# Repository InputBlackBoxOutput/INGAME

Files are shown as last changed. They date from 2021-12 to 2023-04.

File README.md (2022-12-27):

# INGAME

INGAME is a motion emulator with virtual reality features for playing first person
shooting/adventure games. Virtual reality (VR) is a simulated experience that can be similar to
or completely different from the real world. INGAME has been designed to provide the user
with the feeling of being 'IN-the-GAME'. INGAME is modular in nature and consists of the
following modules.

1. HID module
1. Controller module
1. Pedometer module
1. VR headset

The first three modules listed above have been explained in detail later in the document. The
VR headset provides split stereo video to the user. The following image shows the functional
block diagram of the INGAME system 

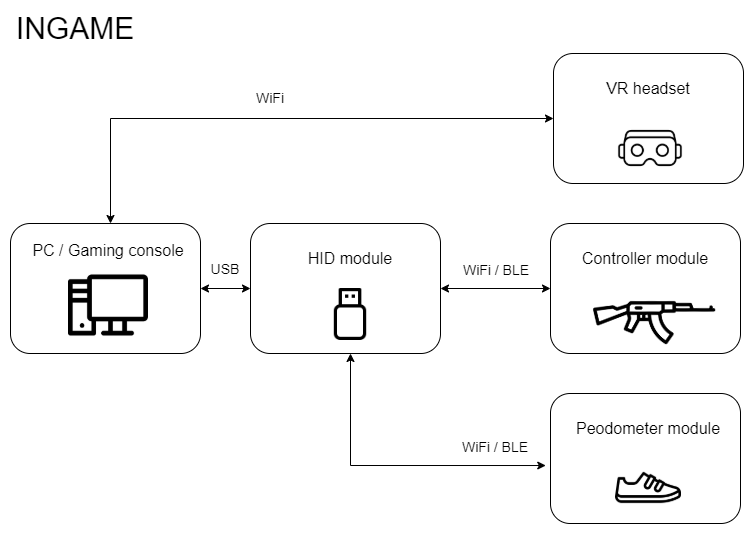
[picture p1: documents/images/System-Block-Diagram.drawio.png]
System block diagram


## Salient features
* Modular to support addons
* Tangle free gaming since the entire system is wireless
* Adaptable to any first person shooting/adventure game
* Minimal lag during gaming due to high-speed data transfer
* Power saving mode to make the battery last longer
* Product certifications: CE certified and ROHS compliant 

## HID module 

### Functions 
- Act as a wireless gateway between the modules worn by the user and the computer
- Connect with the computer via USB as an HID device
- Receive data wirelessly and then map the data to controls of the selected game and send appropriate key strokes to the computer
- Switch the game controls mapping depending on the user selected game
- Display a menu showing information about the system

## Controller module

### Functions
- Connect with the HID module wirelessly
- Send data associated with a button when a button is pressed
- Read IMU data, compute equivalent mouse movement and send the data to the HID module
- Calibrate the IMU device when the calibration button is pressed
- Monitor battery level and sound a buzzer when the battery is low
- Switch to power saving mode upon user inactivity
- [Optional] Control a vibration motor to simulate gunfire which increases in intensity per trigger button press

## Pedometer module

### Functions
- Connect with the HID module wirelessly
- Read accelerometer data, detect steps and send the data to the HID module
- Calibrate the IMU device when the calibration button is pressed
- Monitor battery level and sound a buzzer when the battery is low
- Switch to power saving mode upon user inactivity

### Made with lots of ⏱️, 📚 and ☕ by InputBlackBoxOutput

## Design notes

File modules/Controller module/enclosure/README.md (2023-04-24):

# Enclosure for controller module

- Option 1: 3D print the toy rifle using the 3D model files in this directory after modification to hold all the PCBs

- Option 2: Buy toy rifles from thrid party and then 3D print modifications to hold all PCBs

|#| Vendor |
|--|--|
|1|https://www.alibaba.com/product-detail/95cm-length-big-operated-lithium-battery_1600554537975.html|
|2|https://www.alibaba.com/product-detail/Boxu-416D-F668-Electric-M416-Toy_1600747761612.html|

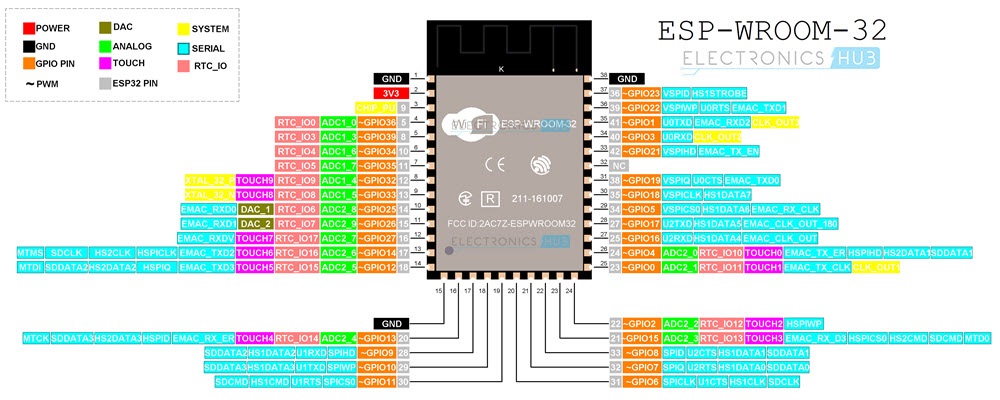
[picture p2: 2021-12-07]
documents/reference circuits/ESP-WROOM-32-Pinout.jpg

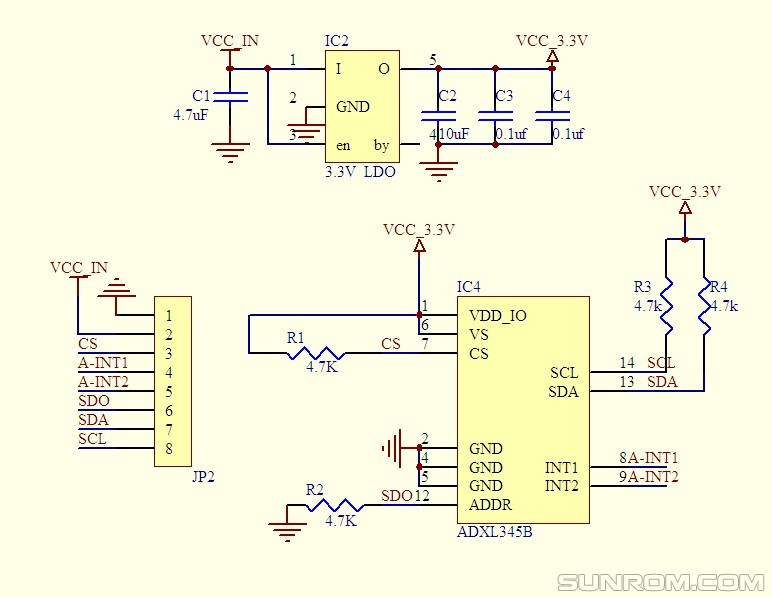
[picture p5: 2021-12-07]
documents/reference circuits/ADXL345 - Accelerometer.jpg

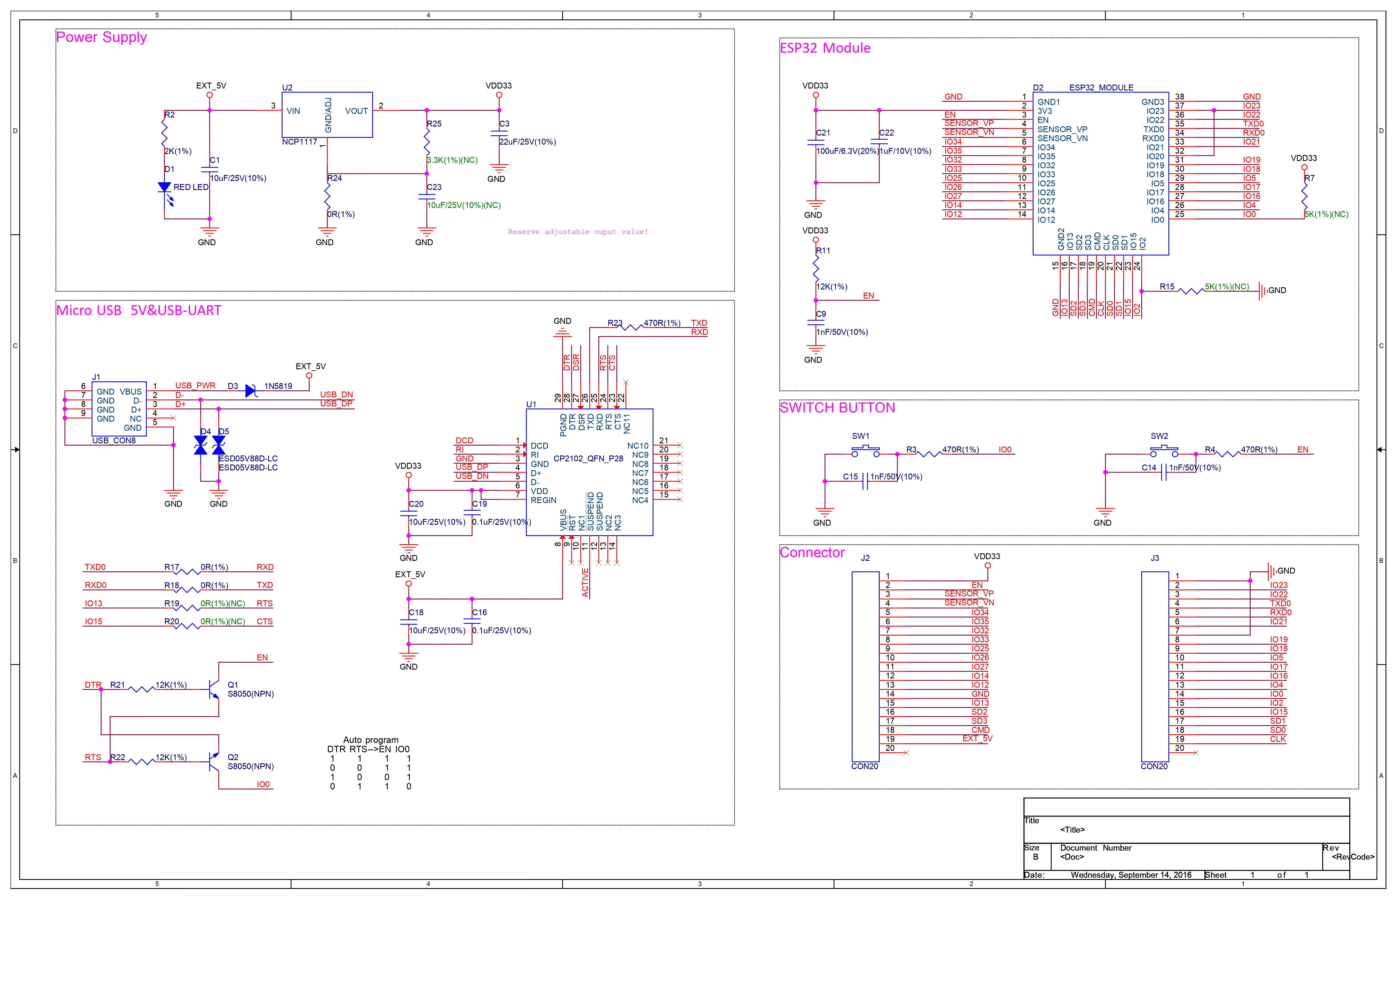
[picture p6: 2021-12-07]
documents/reference circuits/ESP32 - Dev Kit C.jpg

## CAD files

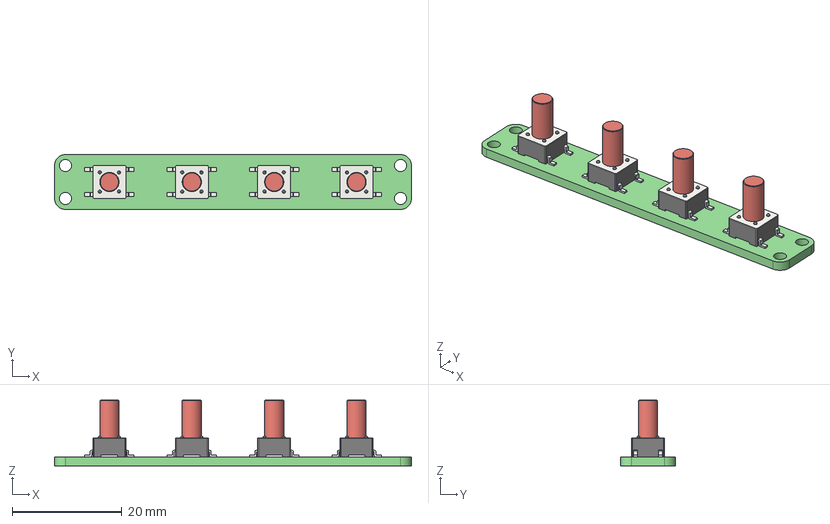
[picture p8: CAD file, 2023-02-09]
modules/Controller module/button-board-1/board.step
65.0 x 10.0 x 12.0 mm

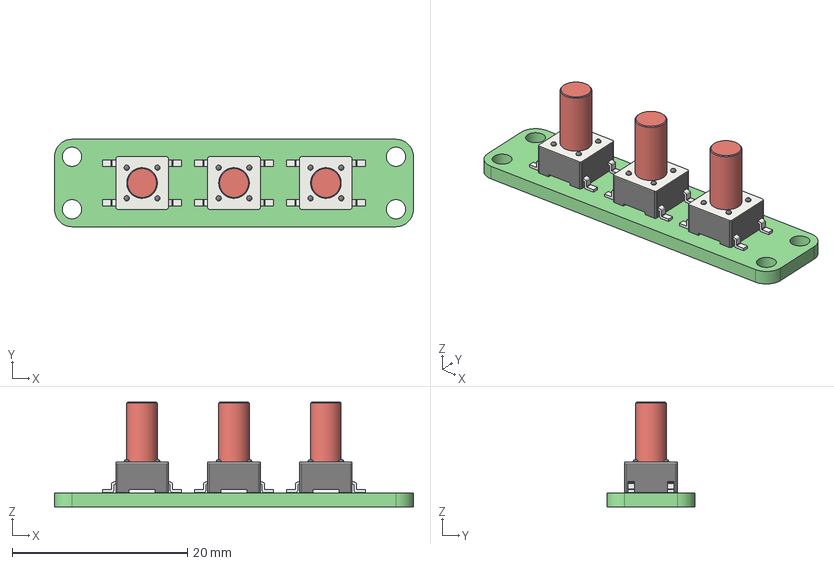
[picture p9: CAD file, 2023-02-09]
modules/Controller module/button-board-2/board.step
41.0 x 10.0 x 12.0 mm

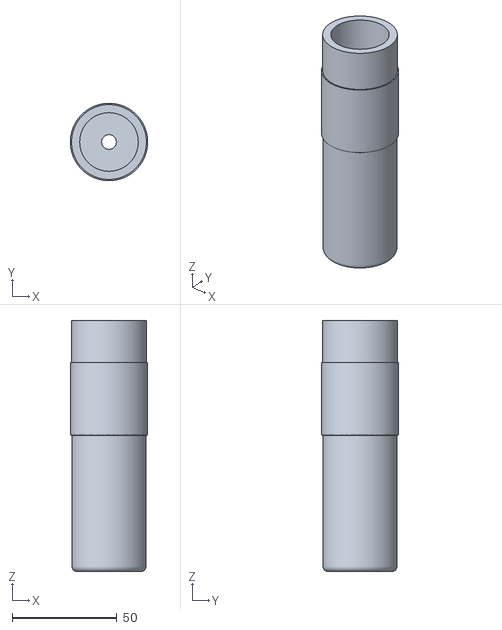
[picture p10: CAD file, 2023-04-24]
modules/Controller module/enclosure/3D-model-files/Suppressor.stl
37.0 x 37.0 x 120.0

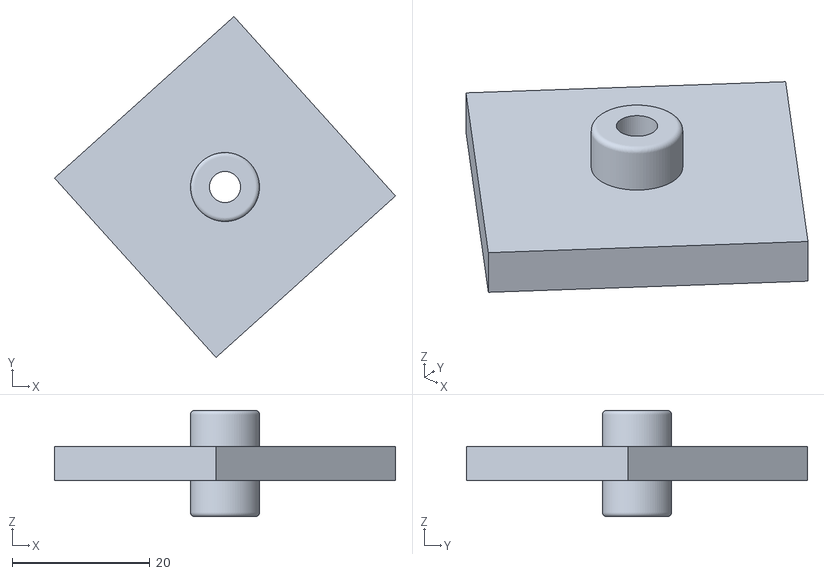
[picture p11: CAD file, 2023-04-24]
modules/Controller module/enclosure/3D-model-files/Gear.stl
49.4 x 49.4 x 15.4

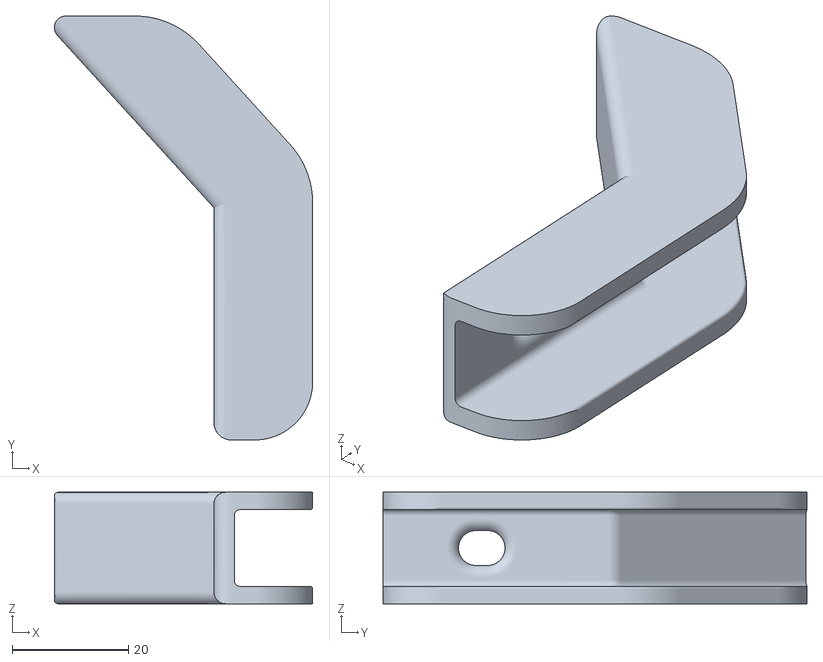
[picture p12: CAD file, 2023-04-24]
modules/Controller module/enclosure/3D-model-files/Stock_lever.stl
44.5 x 73.0 x 19.2

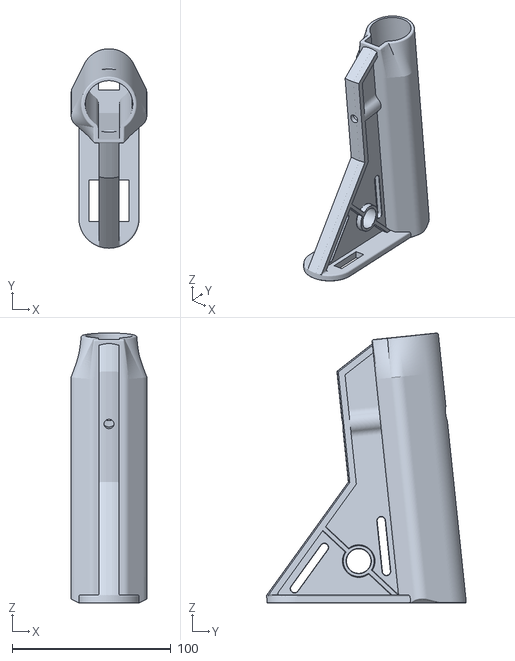
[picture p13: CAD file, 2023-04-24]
modules/Controller module/enclosure/3D-model-files/Stock_body.stl
47.6 x 125.6 x 170.0

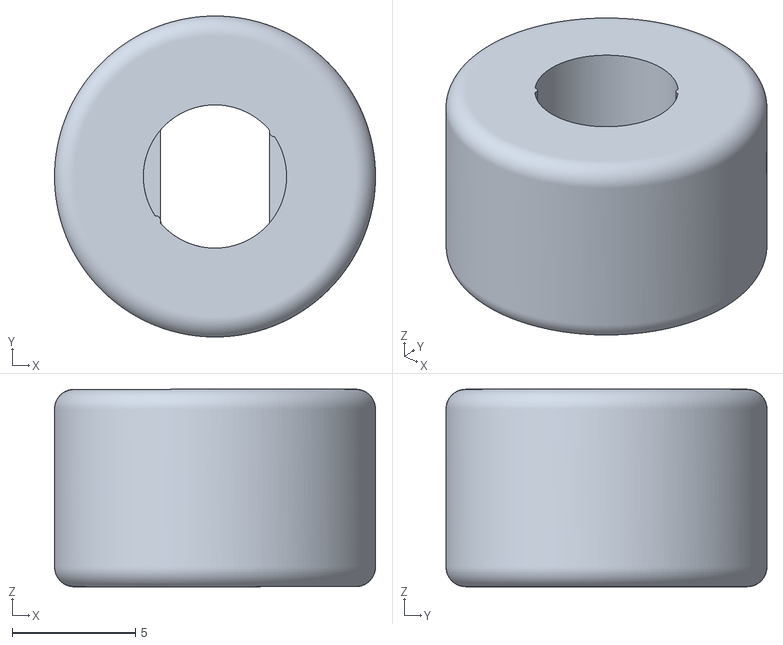
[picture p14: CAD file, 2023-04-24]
modules/Controller module/enclosure/3D-model-files/Stock_pin_cap.stl
13.0 x 13.0 x 8.01

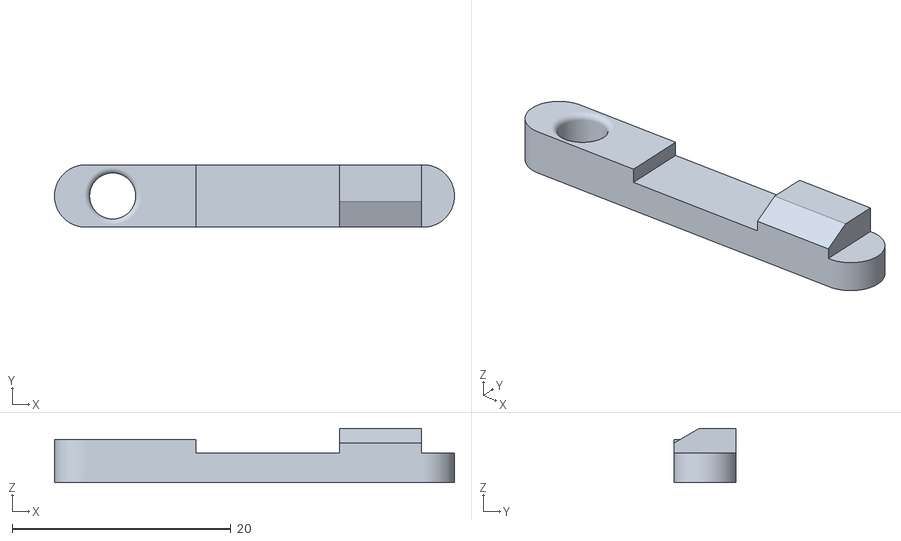
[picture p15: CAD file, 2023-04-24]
modules/Controller module/enclosure/3D-model-files/Magcatch.stl
36.5 x 5.70 x 4.96

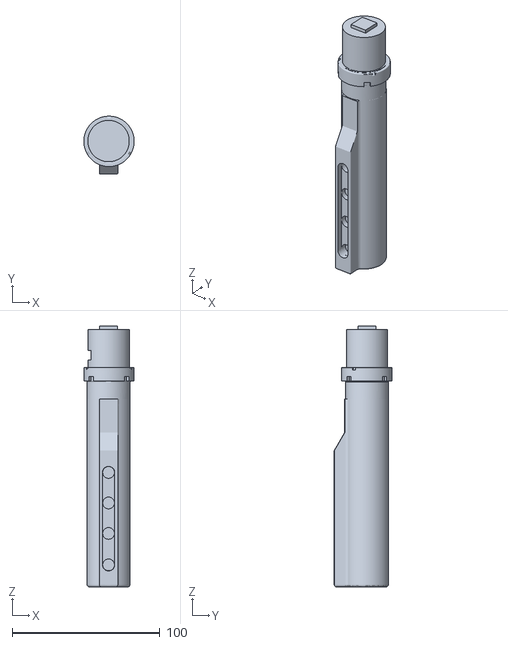
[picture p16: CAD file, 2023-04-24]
modules/Controller module/enclosure/3D-model-files/Buffer_tube.stl
34.1 x 39.0 x 176.7

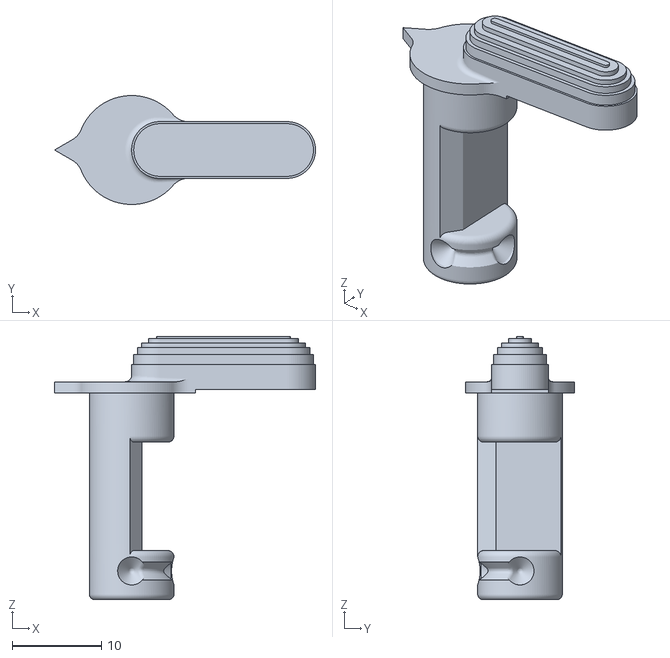
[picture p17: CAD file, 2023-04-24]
modules/Controller module/enclosure/3D-model-files/Safety.stl
29.2 x 12.2 x 29.5

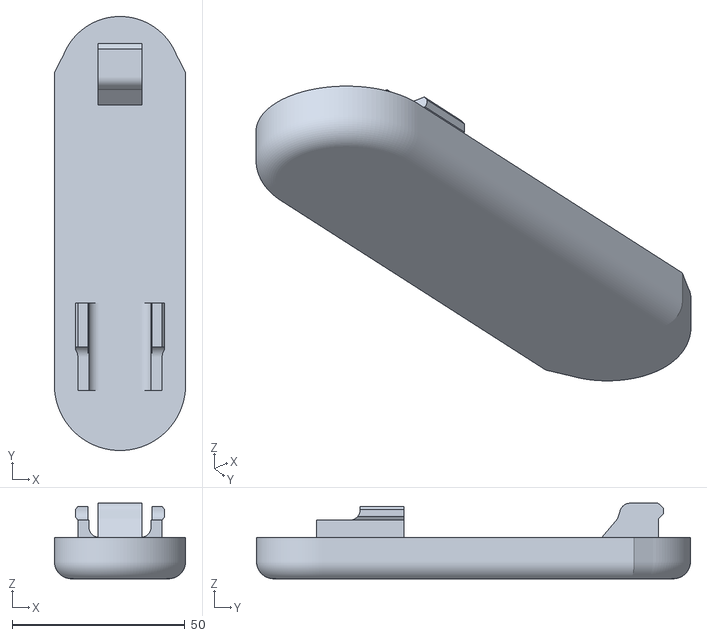
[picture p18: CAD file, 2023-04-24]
modules/Controller module/enclosure/3D-model-files/Stock_pad.stl
38.0 x 125.6 x 21.9

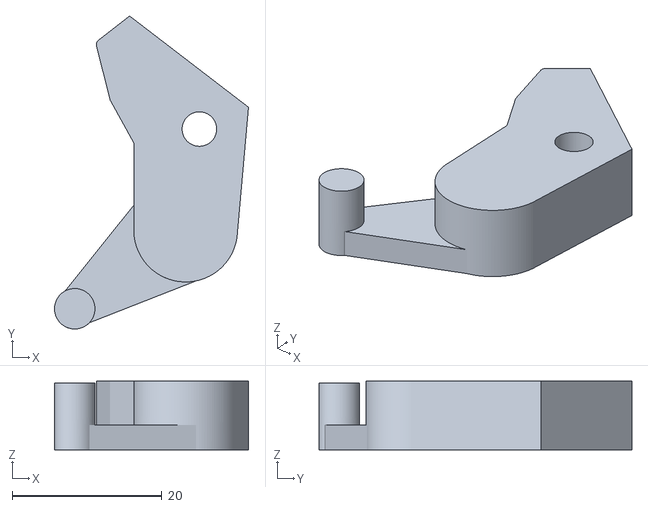
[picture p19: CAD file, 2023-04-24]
modules/Controller module/enclosure/3D-model-files/Disconnector.stl
25.9 x 41.7 x 9.17

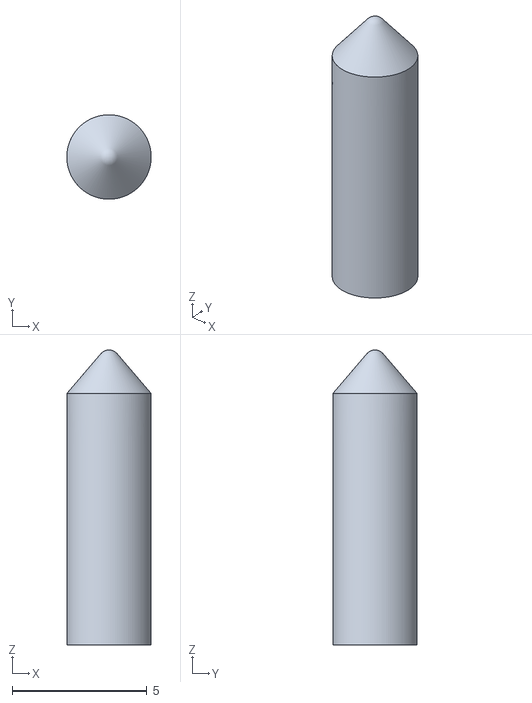
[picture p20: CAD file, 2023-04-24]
modules/Controller module/enclosure/3D-model-files/Safety_detent.stl
3.13 x 3.13 x 10.9

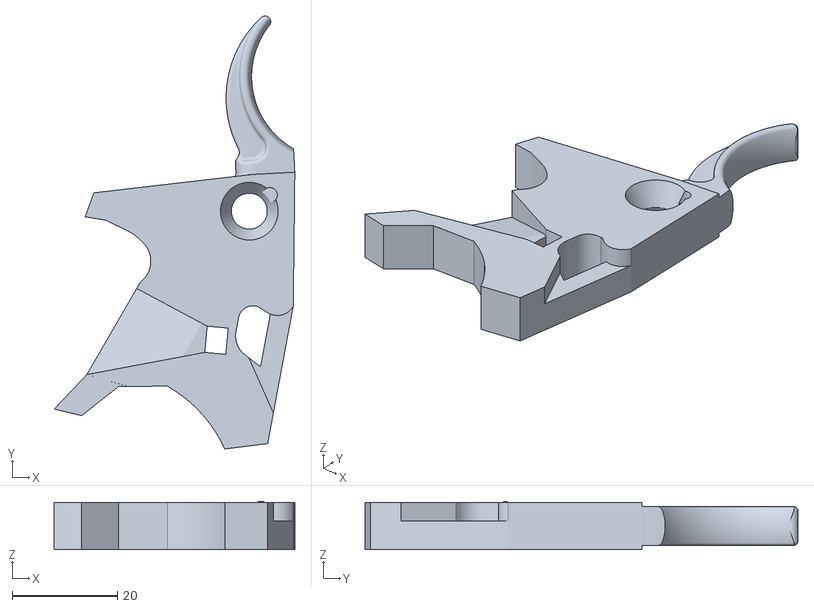
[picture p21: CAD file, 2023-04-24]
modules/Controller module/enclosure/3D-model-files/Trigger.stl
45.7 x 82.2 x 9.17

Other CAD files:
modules/Controller module/enclosure/3D-model-files/Handguard_plug.stl
modules/Controller module/enclosure/3D-model-files/Magcatch_button.stl
modules/Controller module/enclosure/3D-model-files/End_plate.stl
modules/Controller module/enclosure/3D-model-files/Trigger_guard.stl
modules/Controller module/enclosure/3D-model-files/Handguard.stl
modules/Controller module/enclosure/3D-model-files/Stock_pin.stl
modules/HID module/enclosure.f3d
modules/Pedometer module/enclosure.f3d

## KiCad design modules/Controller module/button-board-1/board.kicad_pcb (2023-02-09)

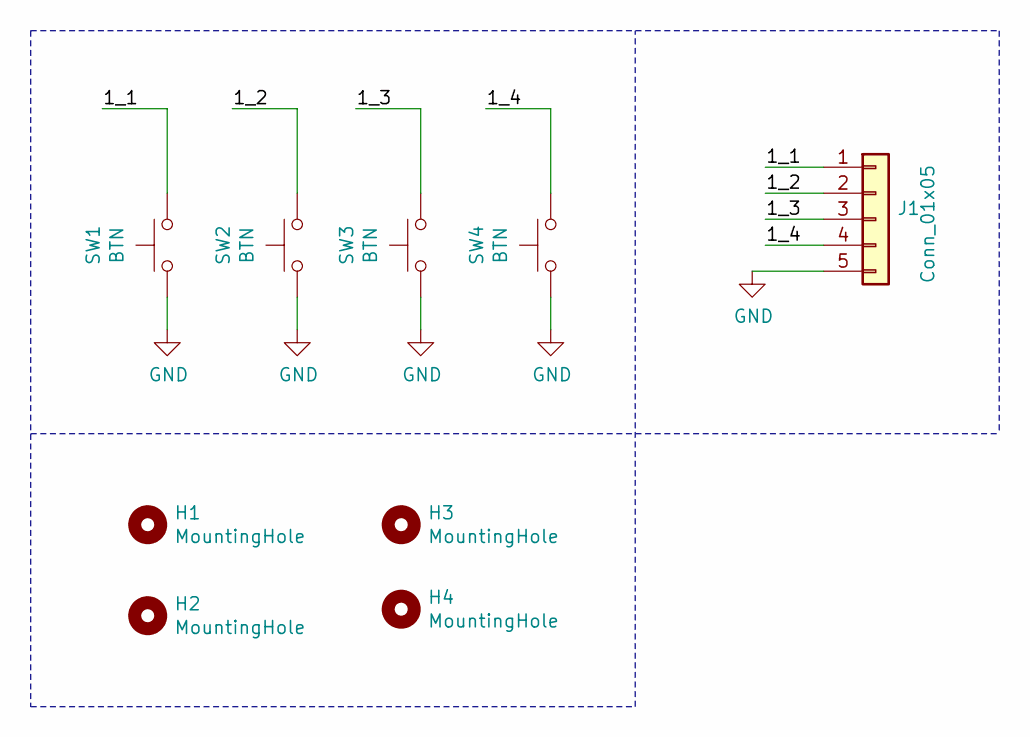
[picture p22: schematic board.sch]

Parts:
H1, H2, H3, H4: MountingHole; MountingHole_2.2mm_M2
J1: Conn_01x05; SolderWire_1x05_P2.54mm
SW1, SW2, SW3, SW4: BTN; SW_SPST_Omron_B3FS-100xP

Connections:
/1_1: J1.1, SW1.2
/1_2: J1.2, SW2.2
/1_3: J1.3, SW3.2
/1_4: J1.4, SW4.2
GND: J1.5, SW1.1, SW2.1, SW3.1, SW4.1

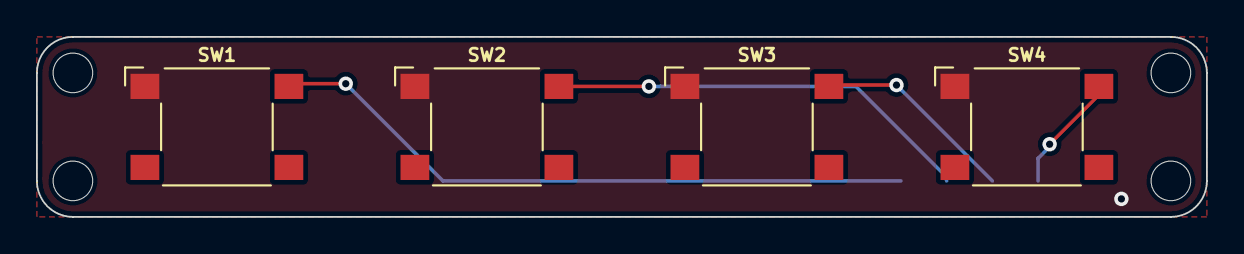
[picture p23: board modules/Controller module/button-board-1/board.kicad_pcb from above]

Board: 2 copper layers, 65.0 x 10.0 mm, 9 parts (1 on the bottom side), 5 nets.

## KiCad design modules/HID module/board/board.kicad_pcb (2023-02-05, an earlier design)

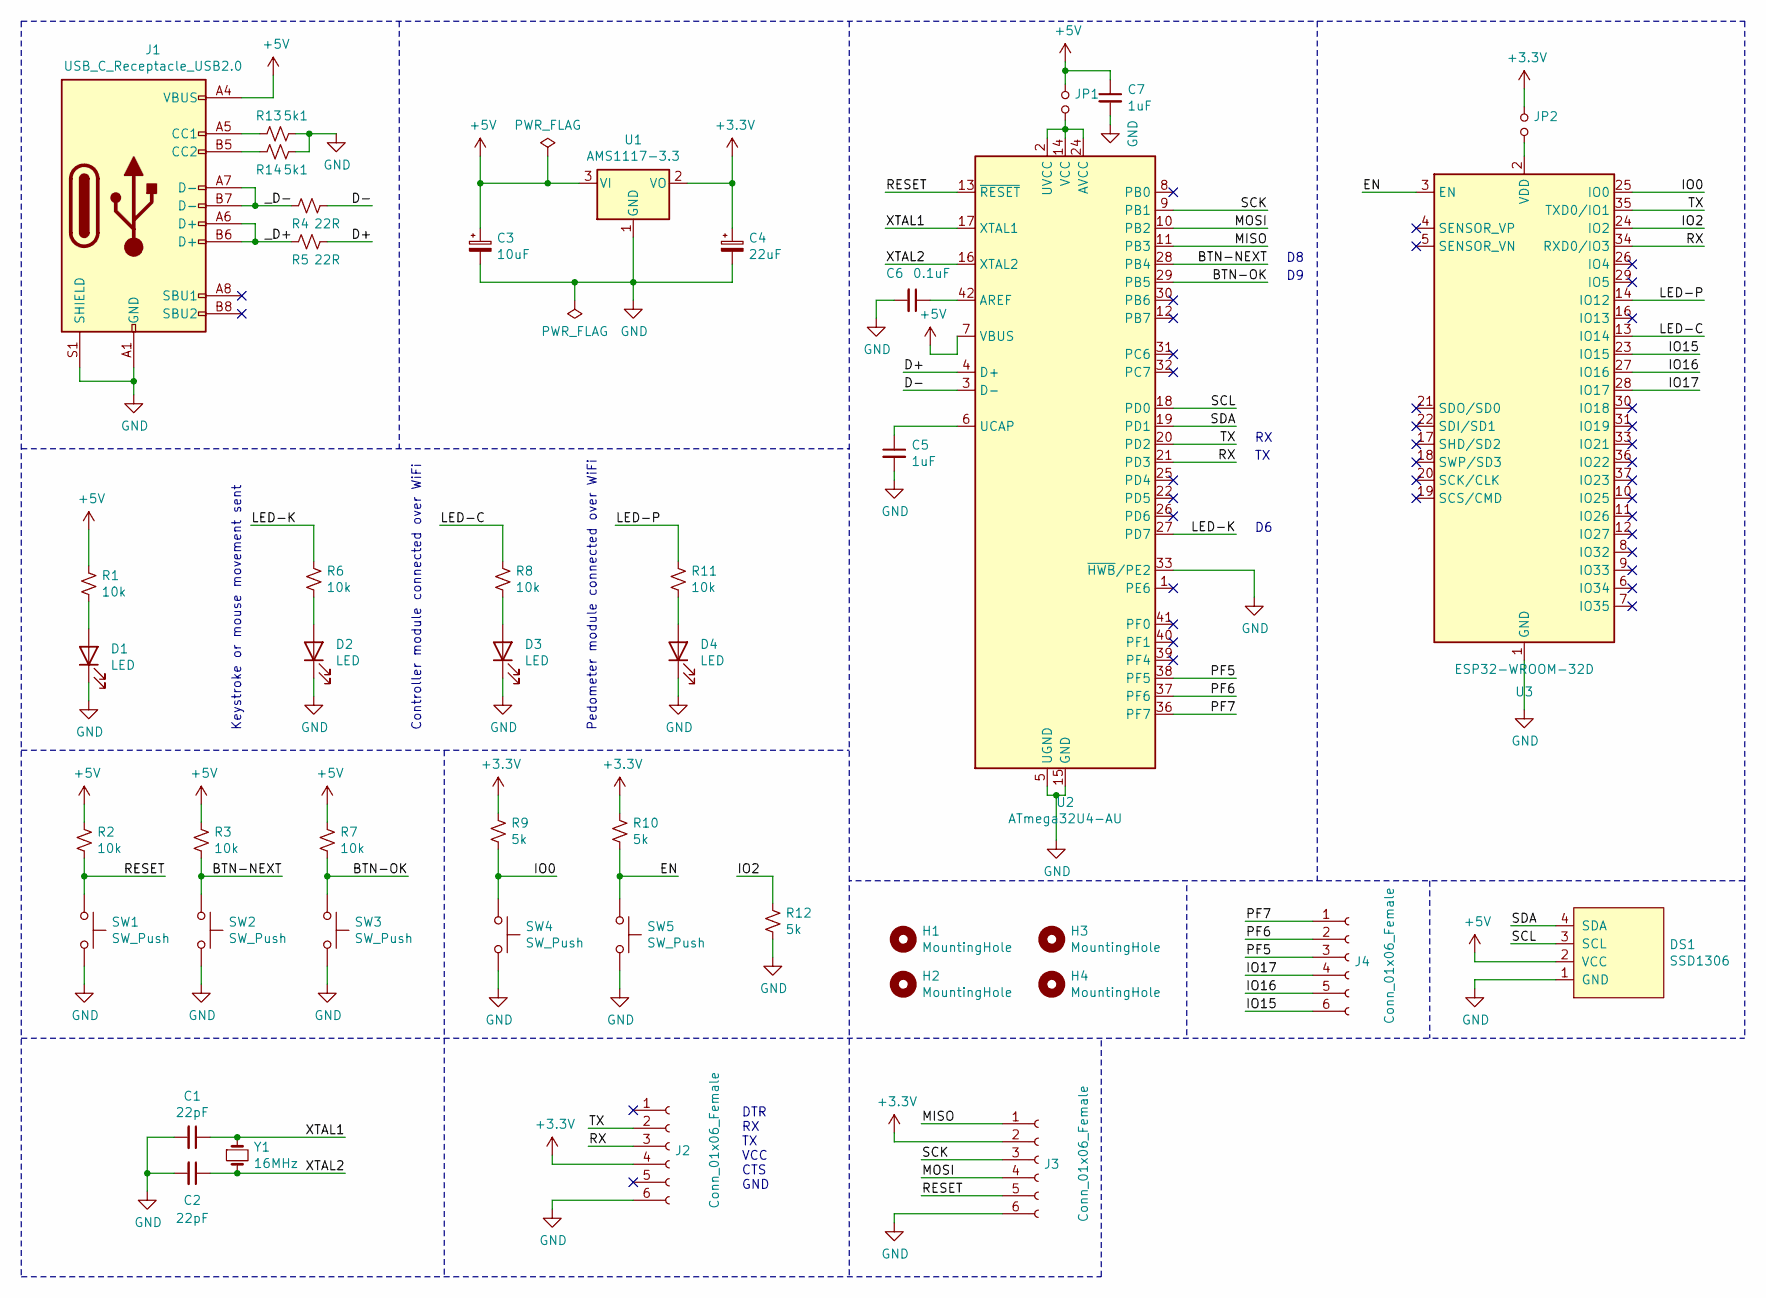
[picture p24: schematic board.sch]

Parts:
C1, C2: 22pF; C_0805_2012Metric_Pad1.18x1.45mm_HandSolder
C3: 10uF; C_0805_2012Metric_Pad1.18x1.45mm_HandSolder
C4: 22uF; C_0805_2012Metric_Pad1.18x1.45mm_HandSolder
C5, C7: 1uF; C_0805_2012Metric_Pad1.18x1.45mm_HandSolder
C6: 0.1uF; C_0805_2012Metric_Pad1.18x1.45mm_HandSolder
D1, D2, D3, D4: LED; LED_0805_2012Metric_Pad1.15x1.40mm_HandSolder
DS1: SSD1306; 128x64OLED
H1, H2, H3, H4: MountingHole; MountingHole_2.2mm_M2
J1: USB_C_Receptacle_USB2.0; USB_C_Receptacle_HRO_TYPE-C-31-M-12
J2, J3, J4: Conn_01x06_Female; SolderWire_1x06_P2.54mm
JP1, JP2: Jumper_NO_Small; SolderJumper-2_P1.3mm_Open_RoundedPad1.0x1.5mm
R1, R2, R3, R6, R7, R8, R11: 10k; R_0805_2012Metric_Pad1.20x1.40mm_HandSolder
R4, R5: 22R; R_0603_1608Metric
R9, R10, R12: 5k; R_0805_2012Metric_Pad1.20x1.40mm_HandSolder
R13, R14: 5k1; R_0603_1608Metric
SW1, SW4, SW5: SW_Push; SW_SPST_B3U-1000P
SW2, SW3: SW_Push; SW_SPST_Omron_B3FS-100xP
U1: AMS1117-3.3; SOT-223-3_TabPin2
U2: ATmega32U4-AU; TQFP-44_10x10mm_P0.8mm
U3: ESP32-WROOM-32D; ESP32-WROOM-32
Y1: 16MHz; Crystal_SMD_HC49-SD

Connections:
+3V3: C4.1, J2.4, J3.2, JP2.1, R9.1, R10.1, U1.2 (VO)
+5V: C3.1, C7.1, DS1.2 (VCC), J1.A4 (VBUS), J1.A9 (VBUS), J1.B4 (VBUS), J1.B9 (VBUS), JP1.1, R1.1, R2.1, R3.1, R7.1, U1.3 (VI), U2.7 (VBUS)
/BTN-NEXT: R3.2, SW2.1, U2.28 (PB4)
/BTN-OK: R7.2, SW3.1, U2.29 (PB5)
/D+: R5.1, U2.4 (D+)
/D-: R4.1, U2.3 (D-)
/EN: R10.2, SW5.1, U3.3 (EN)
/IO0: R9.2, SW4.1, U3.25 (IO0)
/IO2: R12.1, U3.24 (IO2)
/IO15: J4.6, U3.23 (IO15)
/IO16: J4.5, U3.27 (IO16)
/IO17: J4.4, U3.28 (IO17)
/LED-C: R8.1, U3.13 (IO14)
/LED-K: R6.1, U2.27 (PD7)
/LED-P: R11.1, U3.14 (IO12)
/MISO: J3.1, U2.11 (PB3)
/MOSI: J3.4, U2.10 (PB2)
/PF5: J4.3, U2.38 (PF5)
/PF6: J4.2, U2.37 (PF6)
/PF7: J4.1, U2.36 (PF7)
/RESET: J3.5, R2.2, SW1.1, U2.13 (~RESET)
/RX: J2.3, U2.21 (PD3), U3.34 (RXD0/IO3)
/SCK: J3.3, U2.9 (PB1)
/SCL: DS1.3 (SCL), U2.18 (PD0)
/SDA: DS1.4 (SDA), U2.19 (PD1)
/TX: J2.2, U2.20 (PD2), U3.35 (TXD0/IO1)
/XTAL1: C1.1, U2.17 (XTAL1), Y1.1
/XTAL2: C2.1, U2.16 (XTAL2), Y1.2
/_D+: J1.A6 (D+), J1.B6 (D+), R5.2
/_D-: J1.A7 (D-), J1.B7 (D-), R4.2
GND: C1.2, C2.2, C3.2, C4.2, C5.2, C6.2, C7.2, D1.1 (K), D2.1 (K), D3.1 (K), D4.1 (K), DS1.1 (GND), J1.A1 (GND), J1.A12 (GND), J1.B1 (GND), J1.B12 (GND), J1.S1 (SHIELD), J2.6, J3.6, R12.2, R13.1, R14.1, SW1.2, SW2.2, SW3.2, SW4.2, SW5.2, U1.1 (GND), U2.5 (UGND), U2.15 (GND), U2.23 (GND), U2.33 (~HWB~/PE2), U2.35 (GND), U2.43 (GND), U3.1 (GND), U3.15 (GND), U3.38 (GND), U3.39 (GND)
unnamed: C5.1, U2.6 (UCAP)
unnamed: C6.1, U2.42 (AREF)
unnamed: D1.2 (A), R1.2
unnamed: D2.2 (A), R6.2
unnamed: D3.2 (A), R8.2
unnamed: D4.2 (A), R11.2
unnamed: J1.A5 (CC1), R13.2
unnamed: J1.B5 (CC2), R14.2
unnamed: JP1.2, U2.2 (UVCC), U2.14 (VCC), U2.24 (AVCC), U2.34 (VCC), U2.44 (AVCC)
unnamed: JP2.2, U3.2 (VDD)

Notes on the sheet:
Keystroke or mouse movement sent
Controller module connected over WiFi
DTR RX TX VCC CTS GND
Pedometer module connected over WiFi

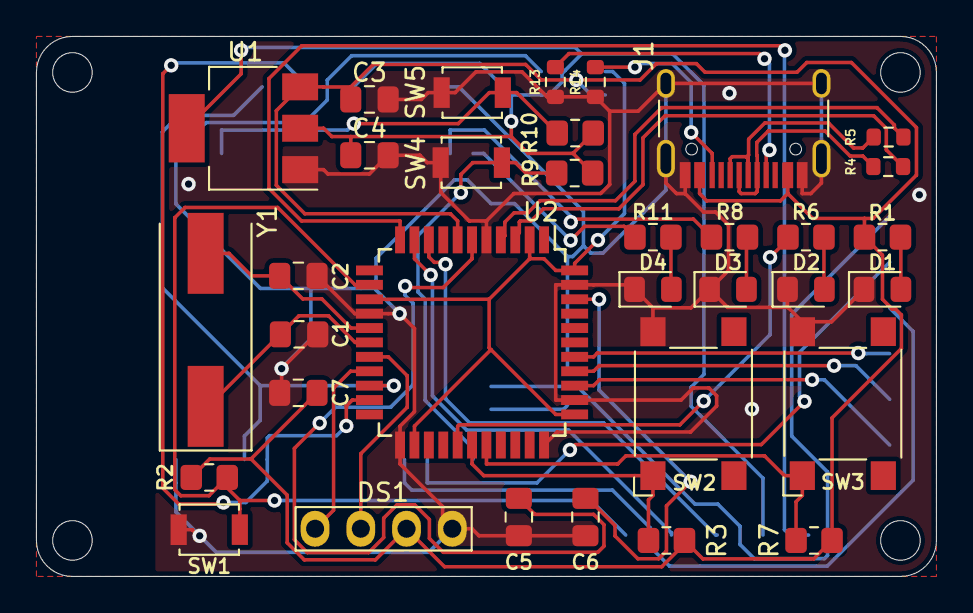
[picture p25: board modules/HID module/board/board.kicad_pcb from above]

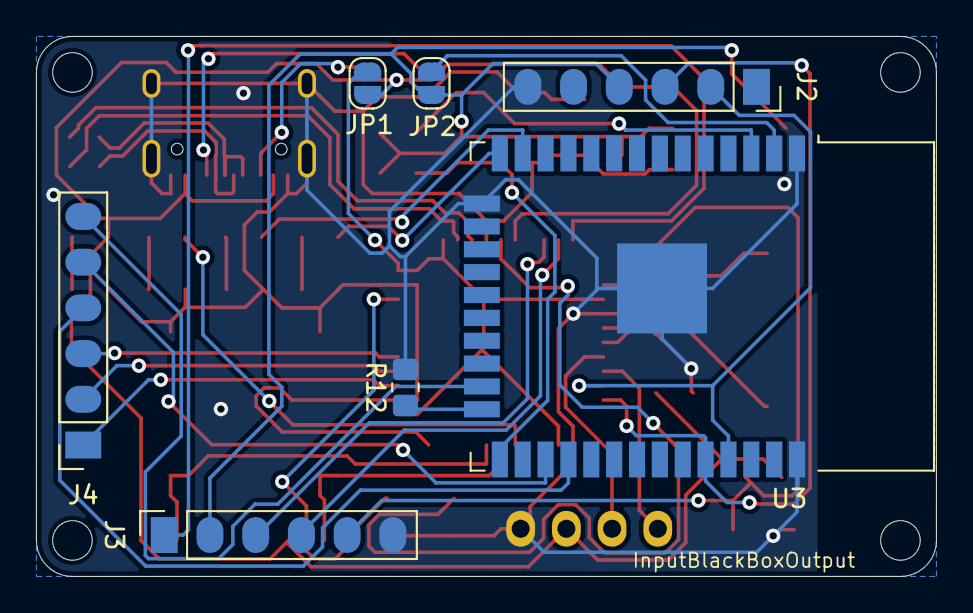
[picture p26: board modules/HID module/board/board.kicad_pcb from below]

Board: 2 copper layers, 50.0 x 30.0 mm, 45 parts (7 on the bottom side), 41 nets.

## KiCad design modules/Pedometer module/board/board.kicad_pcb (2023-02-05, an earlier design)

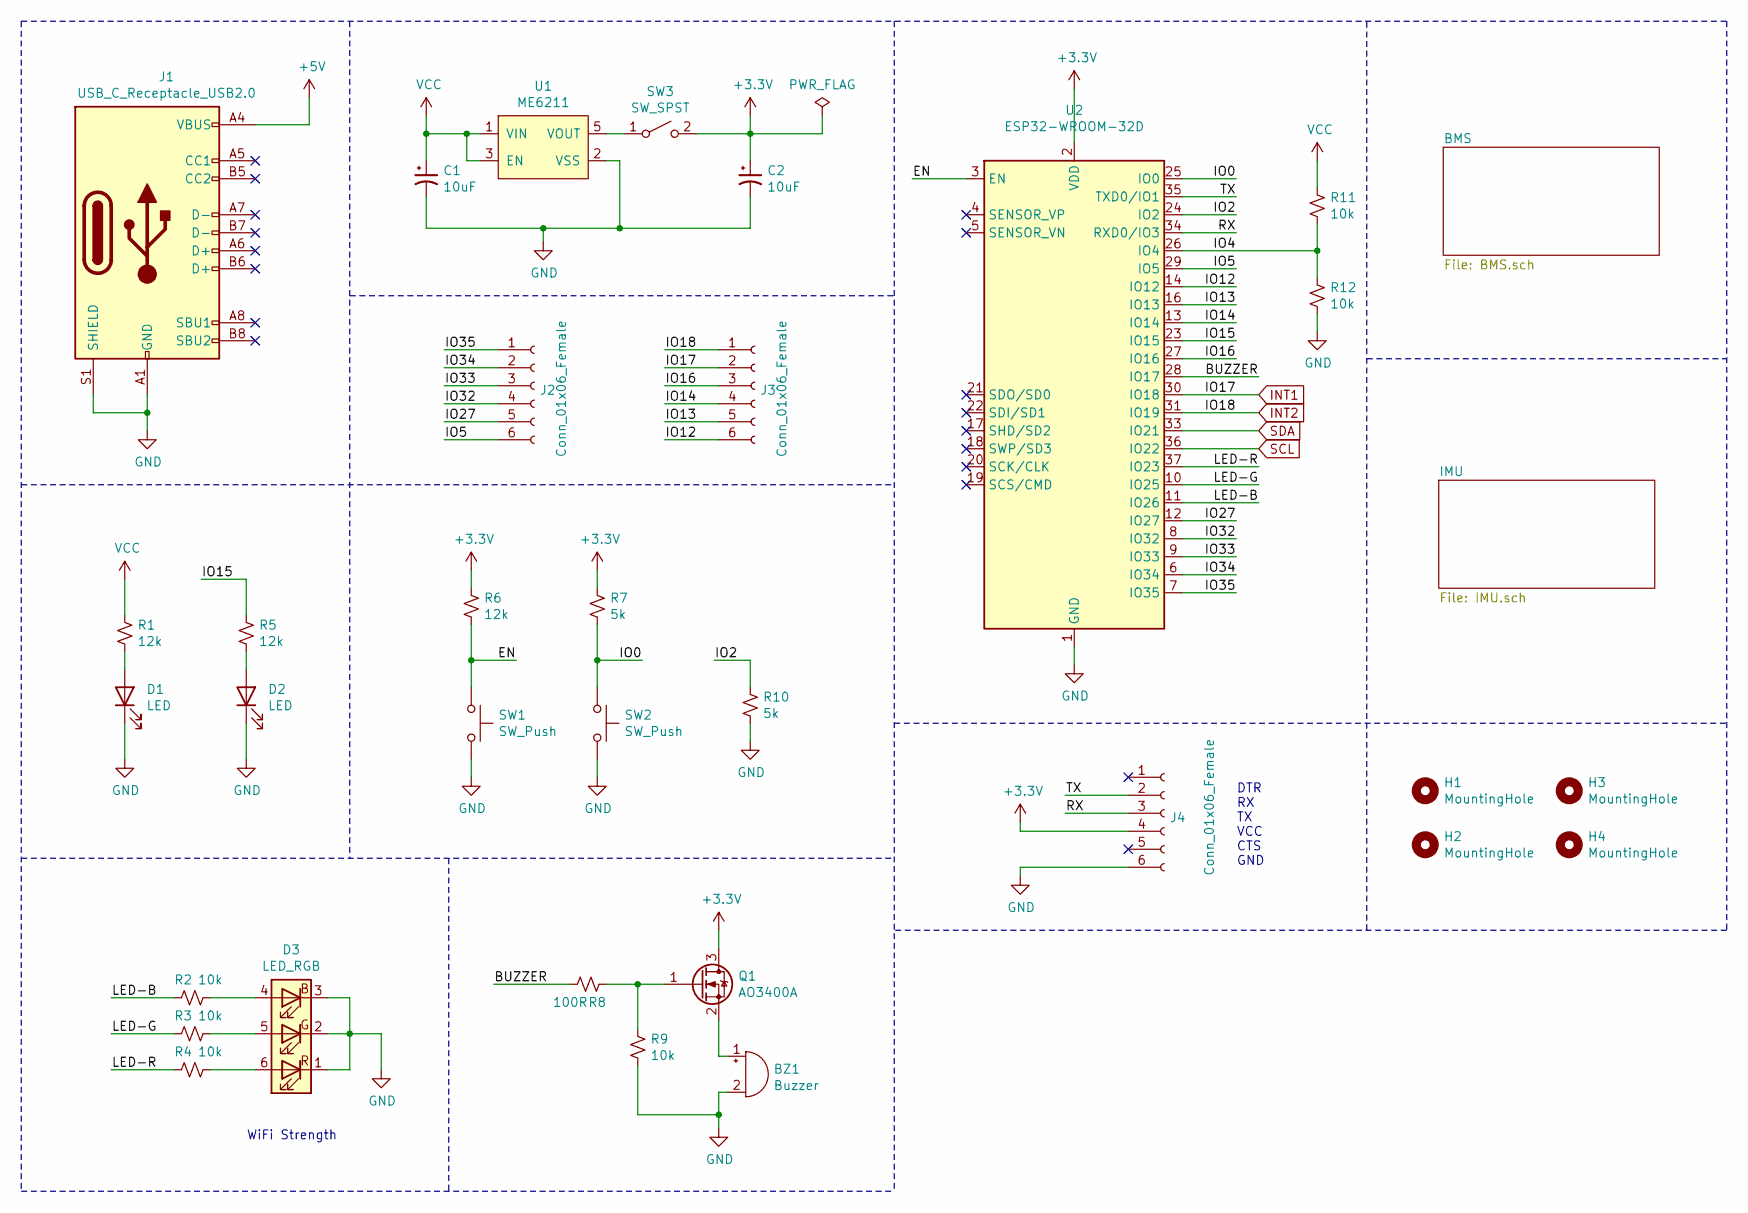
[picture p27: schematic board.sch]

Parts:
BZ1: Buzzer; Buzzer_Murata_PKMCS0909E4000-R1
C1, C2: 10uF; C_0805_2012Metric_Pad1.18x1.45mm_HandSolder
D1, D2: LED; LED_0805_2012Metric_Pad1.15x1.40mm_HandSolder
D3: LED_RGB; LED_RGB_5050-6
H1, H2: MountingHole; MountingHole_2.2mm_M2
H3, H4: MountingHole; MountingHole_2.5mm
J1: USB_C_Receptacle_USB2.0; USB_C_Receptacle_HRO_TYPE-C-31-M-12
J2, J3, J4: Conn_01x06_Female; SolderWire_1x06_P2.54mm
Q1: AO3400A; SOT-23
R1, R5, R6: 12k; R_0805_2012Metric_Pad1.20x1.40mm_HandSolder
R2, R3, R4, R9, R11, R12: 10k; R_0805_2012Metric_Pad1.20x1.40mm_HandSolder
R7, R10: 5k; R_0805_2012Metric_Pad1.20x1.40mm_HandSolder
R8: 100R; R_0805_2012Metric_Pad1.20x1.40mm_HandSolder
SW1, SW2: SW_Push; SW_SPST_B3U-1000P
SW3: SW_SPST; SW-SPDT-PCM12
U1: ME6211; SOT-23-5_HandSoldering
U2: ESP32-WROOM-32D; ESP32-WROOM-32

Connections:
+5V: J1.A4 (VBUS), J1.A9 (VBUS), J1.B4 (VBUS), J1.B9 (VBUS); also elsewhere on the board
/BUZZER: R8.1, U2.28 (IO17)
/EN: R6.2, SW1.1, U2.3 (EN)
/IO0: R7.2, SW2.1, U2.25 (IO0)
/IO2: R10.1, U2.24 (IO2)
/IO4: R11.2, R12.1, U2.26 (IO4)
/IO5: J2.6, U2.29 (IO5)
/IO12: J3.6, U2.14 (IO12)
/IO13: J3.5, U2.16 (IO13)
/IO14: J3.4, U2.13 (IO14)
/IO15: R5.1, U2.23 (IO15)
/IO16: J3.3, U2.27 (IO16)
/IO27: J2.5, U2.12 (IO27)
/IO32: J2.4, U2.8 (IO32)
/IO33: J2.3, U2.9 (IO33)
/IO34: J2.2, U2.6 (IO34)
/IO35: J2.1, U2.7 (IO35)
/LED-B: R2.2, U2.11 (IO26)
/LED-G: R3.2, U2.10 (IO25)
/LED-R: R4.2, U2.37 (IO23)
/RX: J4.3, U2.34 (RXD0/IO3)
/TX: J4.2, U2.35 (TXD0/IO1)
GND: BZ1.2 (+), C1.2, C2.2, D1.1 (K), D2.1 (K), D3.1 (RK), D3.2 (GK), D3.3 (BK), J1.A1 (GND), J1.A12 (GND), J1.B1 (GND), J1.B12 (GND), J1.S1 (SHIELD), J4.6, R9.2, R10.2, R12.2, SW1.2, SW2.2, U1.2 (VSS), U2.1 (GND), U2.15 (GND), U2.38 (GND), U2.39 (GND); also elsewhere on the board
INT1: J3.2, U2.30 (IO18); also elsewhere on the board
INT2: J3.1, U2.31 (IO19); also elsewhere on the board
unnamed: BZ1.1 (-), Q1.2 (S)
unnamed: D1.2 (A), R1.2
unnamed: D2.2 (A), R5.2
unnamed: D3.4 (BA), R2.1
unnamed: D3.5 (GA), R3.1
unnamed: D3.6 (RA), R4.1
unnamed: Q1.1 (G), R8.2, R9.1
unnamed: SW3.1 (A), U1.5 (VOUT)
SCL: U2.36 (IO22); also elsewhere on the board
SDA: U2.33 (IO21); also elsewhere on the board
VCC: C1.1, R1.1, R11.1, U1.1 (VIN), U1.3 (EN); also elsewhere on the board

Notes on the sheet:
DTR RX TX VCC CTS GND
WiFi Strength

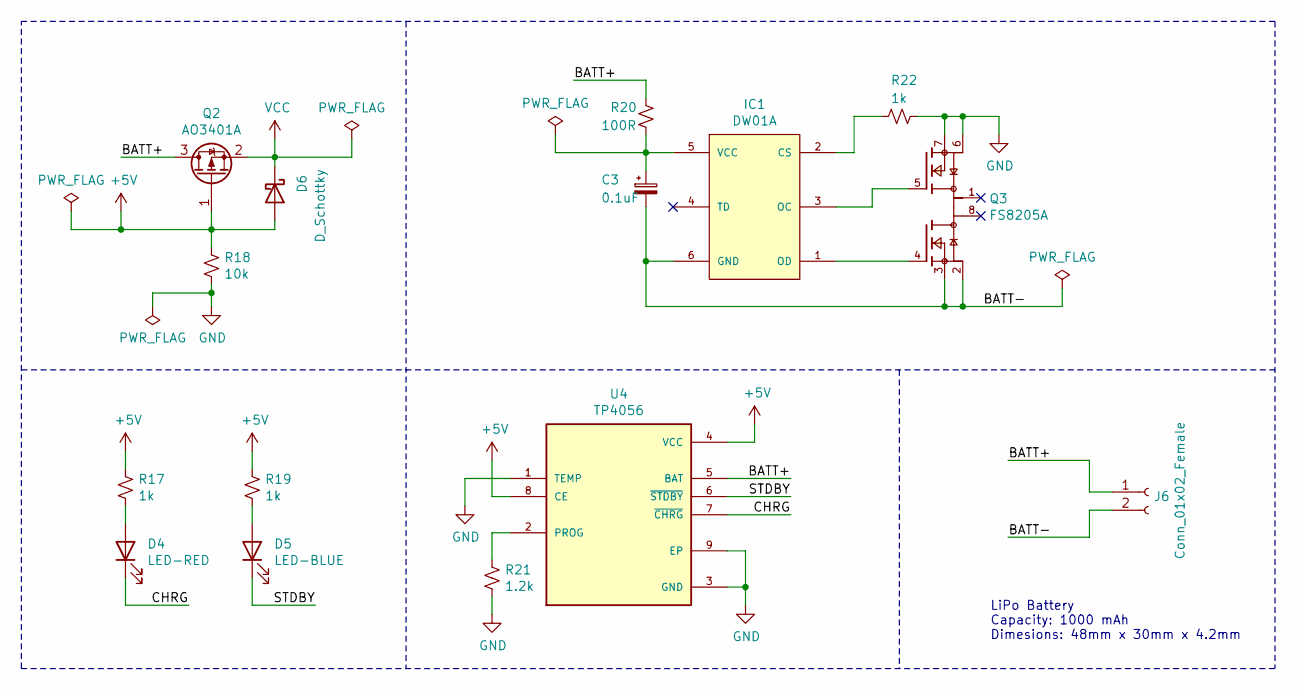
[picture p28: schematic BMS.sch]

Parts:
C3: 0.1uF; C_0805_2012Metric_Pad1.18x1.45mm_HandSolder
D4: LED-RED; LED_0805_2012Metric_Pad1.15x1.40mm_HandSolder
D5: LED-BLUE; LED_0805_2012Metric_Pad1.15x1.40mm_HandSolder
D6: D_Schottky; D_SMA
IC1: DW01A; SOT-23-6_Handsoldering; MPN DW01A; LCSC C351410
J6: Conn_01x02_Female; SolderWire_1x02_P2.00mm
Q2: AO3401A; SOT-23
Q3: FS8205A; SOP65P640X120-8N; PARTREV 1.7
R17, R19, R22: 1k; R_0805_2012Metric_Pad1.20x1.40mm_HandSolder
R18: 10k; R_0805_2012Metric_Pad1.20x1.40mm_HandSolder
R20: 100R; R_0805_2012Metric_Pad1.20x1.40mm_HandSolder
R21: 1.2k; R_0805_2012Metric_Pad1.20x1.40mm_HandSolder
U4: TP4056; SOP127P600X175-9N

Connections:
+5V: D6.2 (A), Q2.1 (G), R17.1, R18.1, R19.1, U4.4 (VCC), U4.8 (CE); also elsewhere on the board
/BMS/BATT+: J6.1, Q2.3 (D), R20.1, U4.5 (BAT)
/BMS/BATT-: C3.2, IC1.6 (GND), J6.2, Q3.2, Q3.3
/BMS/CHRG: D4.1 (K), U4.7 (~CHRG)
/BMS/STDBY: D5.1 (K), U4.6 (~STDBY)
GND: Q3.6, Q3.7, R18.2, R21.2, R22.1, U4.1 (TEMP), U4.3 (GND), U4.9 (EP); also elsewhere on the board
unnamed: C3.1, IC1.5 (VCC), R20.2
unnamed: D4.2 (A), R17.2
unnamed: D5.2 (A), R19.2
unnamed: IC1.1 (OD), Q3.4
unnamed: IC1.2 (CS), R22.2
unnamed: IC1.3 (OC), Q3.5
unnamed: R21.1, U4.2 (PROG)
VCC: D6.1 (K), Q2.2 (S); also elsewhere on the board

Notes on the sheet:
LiPo Battery Capacity: 1000 mAh Dimesions: 48mm x 30mm x 4.2mm

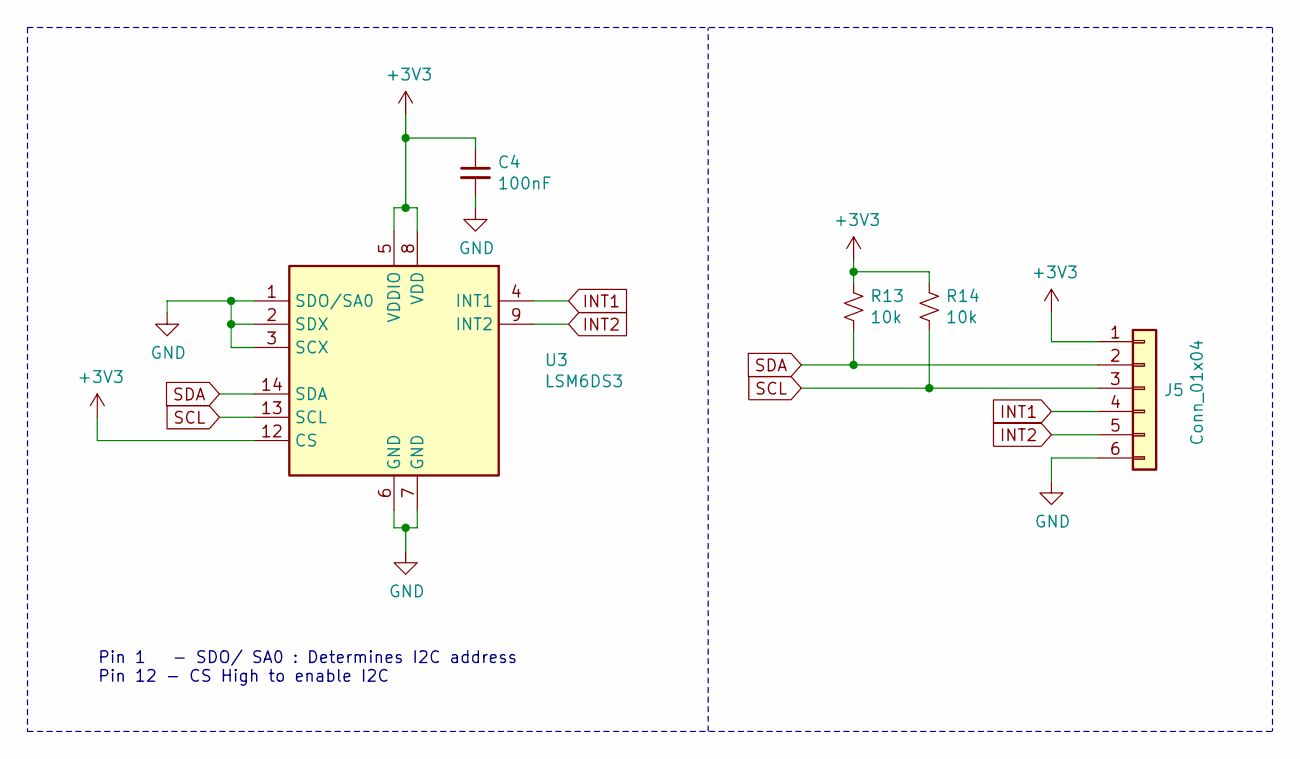
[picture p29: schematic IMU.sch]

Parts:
C4: 100nF; C_0603_1608Metric_Pad1.08x0.95mm_HandSolder
J5: Conn_01x04; SolderWire_1x06_P2.54mm
R13, R14: 10k; R_0603_1608Metric_Pad0.98x0.95mm_HandSolder
U3: LSM6DS3; LGA-14_3x2.5mm_P0.5mm_LayoutBorder3x4y

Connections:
GND: C4.2, J5.6, U3.1 (SDO/SA0), U3.2 (SDX), U3.3 (SCX), U3.6 (GND), U3.7 (GND); also elsewhere on the board
INT1: J5.4, U3.4 (INT1); also elsewhere on the board
INT2: J5.5, U3.9 (INT2); also elsewhere on the board
SCL: J5.3, R14.1, U3.13 (SCL); also elsewhere on the board
SDA: J5.2, R13.1, U3.14 (SDA); also elsewhere on the board

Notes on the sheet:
Pin 1 - SDO/ SA0 : Determines I2C address Pin 12 - CS High to enable I2C

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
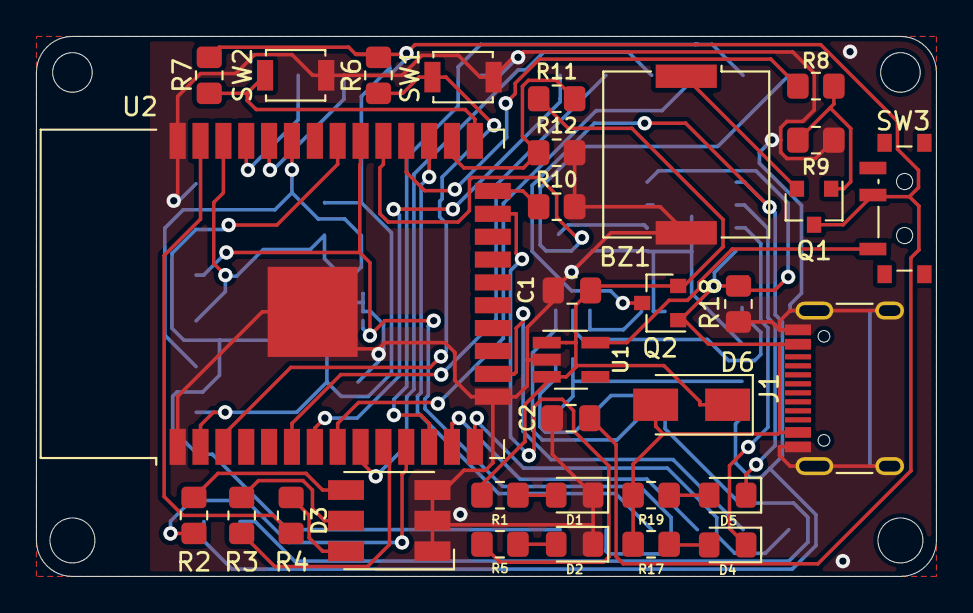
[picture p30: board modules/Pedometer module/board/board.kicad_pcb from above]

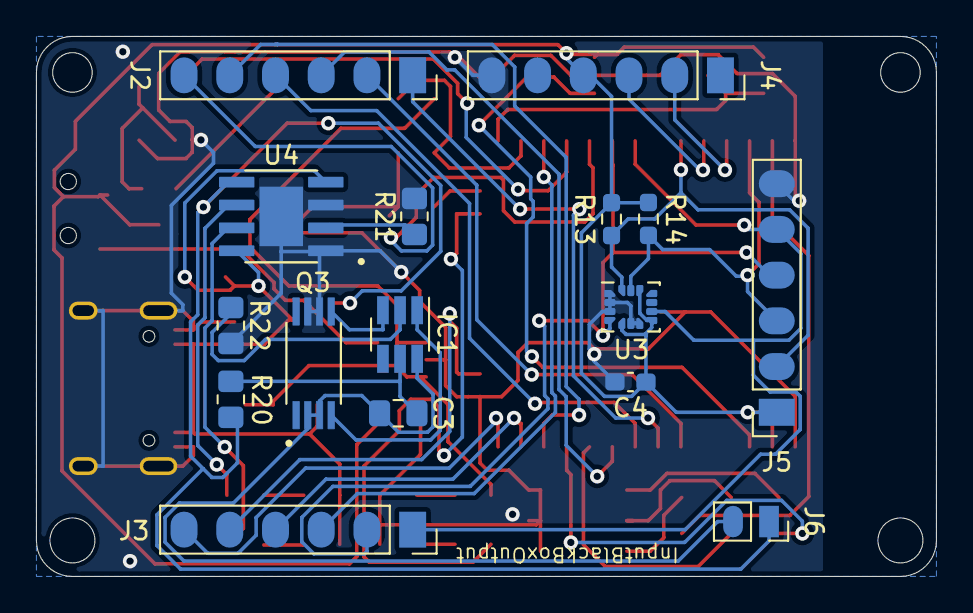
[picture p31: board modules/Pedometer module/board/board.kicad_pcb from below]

Board: 2 copper layers, 50.0 x 30.0 mm, 52 parts (16 on the bottom side), 48 nets.

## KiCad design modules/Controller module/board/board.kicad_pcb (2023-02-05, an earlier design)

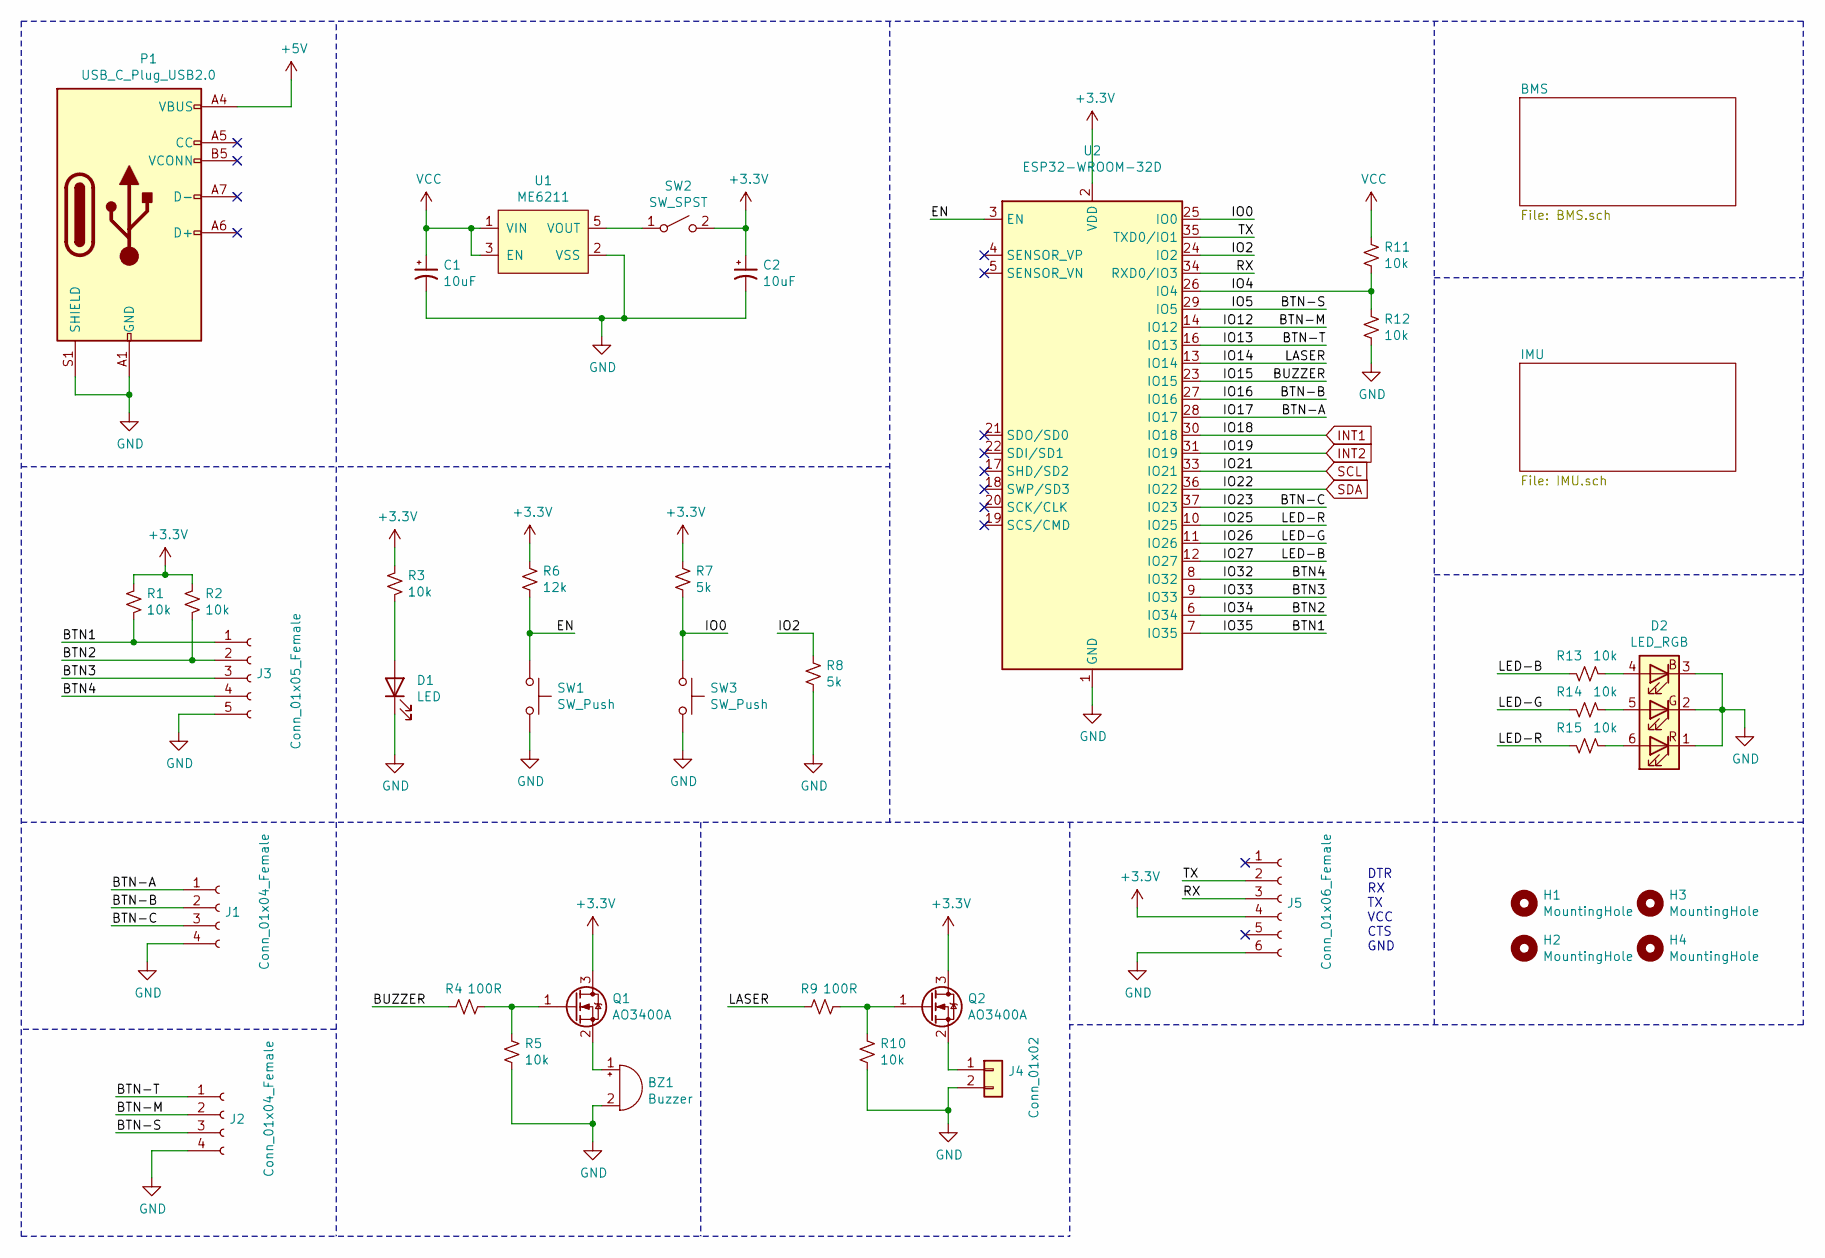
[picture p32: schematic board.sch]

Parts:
BZ1: Buzzer; Buzzer_Murata_PKMCS0909E4000-R1
C1, C2: 10uF; C_0805_2012Metric_Pad1.18x1.45mm_HandSolder
D1: LED; LED_0805_2012Metric_Pad1.15x1.40mm_HandSolder
D2: LED_RGB; LED_RGB_5050-6
H1, H2, H3, H4: MountingHole; MountingHole_2.2mm_M2
J1, J2: Conn_01x04_Female; SolderWire_1x04_P2.00mm
J3: Conn_01x05_Female; SolderWire_1x05_P2.00mm
J4: Conn_01x02; SolderWire_1x02_P2.00mm
J5: Conn_01x06_Female; SolderWire_1x06_P2.54mm
P1: USB_C_Plug_USB2.0; GCT_USB4151-GF-C_REVA
Q1, Q2: AO3400A; SOT-23
R1, R2, R3, R5, R10, R11, R12, R13, R14, R15: 10k; R_0805_2012Metric_Pad1.20x1.40mm_HandSolder
R4, R9: 100R; R_0805_2012Metric_Pad1.20x1.40mm_HandSolder
R6: 12k; R_0805_2012Metric_Pad1.20x1.40mm_HandSolder
R7, R8: 5k; R_0805_2012Metric_Pad1.20x1.40mm_HandSolder
SW1, SW3: SW_Push; SW_SPST_B3U-1000P
SW2: SW_SPST; PinSocket_1x03_P2.54mm_Vertical
U1: ME6211; SOT-23-5_HandSoldering
U2: ESP32-WROOM-32D; ESP32-WROOM-32

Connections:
+3V3: C2.1, J5.4, Q1.3 (D), Q2.3 (D), R1.1, R2.1, R3.1, R6.1, R7.1, SW2.2 (B), U2.2 (VDD); also elsewhere on the board
+5V: P1.A4 (VBUS), P1.A9 (VBUS), P1.B4 (VBUS), P1.B9 (VBUS); also elsewhere on the board
/BTN1: J3.1, R1.2, U2.7 (IO35)
/BTN2: J3.2, R2.2, U2.6 (IO34)
/BTN3: J3.3, U2.9 (IO33)
/BTN4: J3.4, U2.8 (IO32)
/BTN-A: J1.1, U2.28 (IO17)
/BTN-B: J1.2, U2.27 (IO16)
/BTN-C: J1.3, U2.37 (IO23)
/BTN-M: J2.2, U2.14 (IO12)
/BTN-R: J2.3, U2.29 (IO5)
/BTN-T: J2.1, U2.16 (IO13)
/BUZZER: R4.2, U2.23 (IO15)
/EN: R6.2, SW1.1, U2.3 (EN)
/IO0: R7.2, SW3.1, U2.25 (IO0)
/IO2: R8.1, U2.24 (IO2)
/IO4: R11.2, R12.1, U2.26 (IO4)
/IO14: R9.2, U2.13 (IO14)
/IO25: R15.1, U2.10 (IO25)
/IO26: R14.1, U2.11 (IO26)
/IO27: R13.1, U2.12 (IO27)
/RX: J5.3, U2.34 (RXD0/IO3)
/TX: J5.2, U2.35 (TXD0/IO1)
GND: BZ1.2 (+), C1.2, C2.2, D1.1 (K), D2.1 (RK), D2.2 (GK), D2.3 (BK), J1.4, J2.4, J3.5, J4.2, J5.6, P1.A1 (GND), P1.A12 (GND), P1.B1 (GND), P1.B12 (GND), P1.S1 (SHIELD), R5.2, R8.2, R10.2, R12.2, SW1.2, SW3.2, U1.2 (VSS), U2.1 (GND), U2.15 (GND), U2.38 (GND), U2.39 (GND); also elsewhere on the board
INT1: U2.30 (IO18); also elsewhere on the board
INT2: U2.31 (IO19); also elsewhere on the board
unnamed: BZ1.1 (-), Q1.2 (S)
unnamed: D1.2 (A), R3.2
unnamed: D2.4 (BA), R13.2
unnamed: D2.5 (GA), R14.2
unnamed: D2.6 (RA), R15.2
unnamed: J4.1, Q2.2 (S)
unnamed: Q1.1 (G), R4.1, R5.1
unnamed: Q2.1 (G), R9.1, R10.1
unnamed: SW2.1 (A), U1.5 (VOUT)
SCL: U2.33 (IO21); also elsewhere on the board
SDA: U2.36 (IO22); also elsewhere on the board
VCC: C1.1, R11.1, U1.1 (VIN), U1.3 (EN); also elsewhere on the board

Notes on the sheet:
DTR RX TX VCC CTS GND

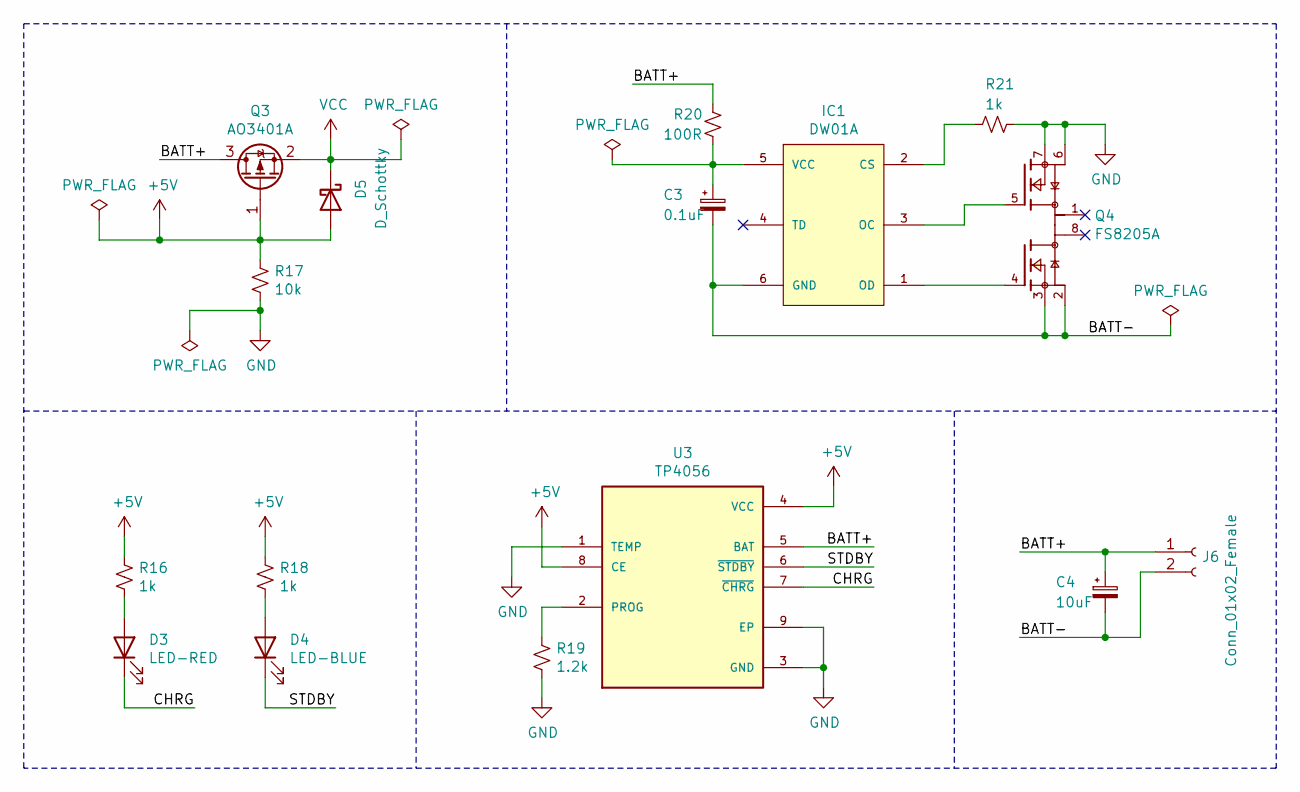
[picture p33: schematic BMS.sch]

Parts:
C3: 0.1uF; C_0805_2012Metric_Pad1.18x1.45mm_HandSolder
C4: 10uF; C_0805_2012Metric_Pad1.18x1.45mm_HandSolder
D3: LED-RED; LED_0805_2012Metric_Pad1.15x1.40mm_HandSolder
D4: LED-BLUE; LED_0805_2012Metric_Pad1.15x1.40mm_HandSolder
D5: D_Schottky; D_SMA
IC1: DW01A; SOT-23-6_Handsoldering; MPN DW01A; LCSC C351410
J6: Conn_01x02_Female; SolderWire_1x02_P2.00mm
Q3: AO3401A; SOT-23
Q4: FS8205A; SOP65P640X120-8N; PARTREV 1.7
R16, R18, R21: 1k; R_0805_2012Metric_Pad1.20x1.40mm_HandSolder
R17: 10k; R_0805_2012Metric_Pad1.20x1.40mm_HandSolder
R19: 1.2k; R_0805_2012Metric_Pad1.20x1.40mm_HandSolder
R20: 100R; R_0805_2012Metric_Pad1.20x1.40mm_HandSolder
U3: TP4056; SOP127P600X175-9N

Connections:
+5V: D5.2 (A), Q3.1 (G), R16.1, R17.1, R18.1, U3.4 (VCC), U3.8 (CE); also elsewhere on the board
/BMS/BATT+: C4.1, J6.1, Q3.3 (D), R20.1, U3.5 (BAT)
/BMS/BATT-: C3.2, C4.2, IC1.6 (GND), J6.2, Q4.2, Q4.3
/BMS/CHRG: D3.1 (K), U3.7 (~CHRG)
/BMS/STDBY: D4.1 (K), U3.6 (~STDBY)
GND: Q4.6, Q4.7, R17.2, R19.2, R21.1, U3.1 (TEMP), U3.3 (GND), U3.9 (EP); also elsewhere on the board
unnamed: C3.1, IC1.5 (VCC), R20.2
unnamed: D3.2 (A), R16.2
unnamed: D4.2 (A), R18.2
unnamed: IC1.1 (OD), Q4.4
unnamed: IC1.2 (CS), R21.2
unnamed: IC1.3 (OC), Q4.5
unnamed: R19.1, U3.2 (PROG)
VCC: D5.1 (K), Q3.2 (S); also elsewhere on the board


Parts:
C5: 100nF; C_0603_1608Metric_Pad1.08x0.95mm_HandSolder
C6: 2.2uF; C_0603_1608Metric_Pad1.08x0.95mm_HandSolder
J7: Conn_01x06_Male; SolderWire_1x06_P2.54mm
R22, R23: 10k; R_0603_1608Metric_Pad0.98x0.95mm_HandSolder
U4: ASM330LHHXTR
U5: MMC5603NJ

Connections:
+3V3: C5.1, C6.1, J7.6, R22.1, R23.1, U4.5 (Vdd_IO), U4.8 (Vdd), U4.12 (CS), U5.B1 (VDD); also elsewhere on the board
GND: C5.2, C6.2, J7.1, U4.1 (SDO/SA0), U4.2 (MSDA), U4.3 (MSCL), U4.7 (GND), U5.A1 (VSA); also elsewhere on the board
INT1: J7.3, U4.4 (INT1); also elsewhere on the board
INT2: J7.2, U4.9 (INT2); also elsewhere on the board
SCL: J7.5, R22.2, U4.13 (SCL), U5.A2 (SCL); also elsewhere on the board
SDA: J7.4, R23.2, U4.14 (SDA), U5.B2 (SDA); also elsewhere on the board



Board: 2 copper layers, 50.0 x 30.0 mm, 60 parts (27 on the bottom side), 49 nets.

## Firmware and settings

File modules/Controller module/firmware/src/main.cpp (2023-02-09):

#include <Arduino.h>
#include "connections.h"
#include "IMU.h"
#include "IMU-Fusion.h"
#include "character-map.h"

#include <WiFi.h>
#include <esp_now.h>

// TODO
// - Auto recalibration
// - Turn lazer on for calibration
// - Switch to power saving if inactivity
// - Offset self calibration
// - Implement trigonometric mapping & scaling for mouse movement

// LINKING FUNCTIONS WITH BUTTONS
#define FIRE B31_PIN
#define SCOPE B32_PIN
#define RELOAD B33_PIN

#define SELECT_1 B21_PIN
#define SELECT_2 B22_PIN

#define FUNC_1 B11_PIN
#define FUNC_2 B12_PIN
#define FUNC_3 B13_PIN
#define FUNC_4 B14_PIN

#define DEBOUNCE_DELAY 15 // ms
#define LOOP_DELAY 50 //ms

boolean buttonRead(uint8_t pin)
{
  if (!digitalRead(pin)) {
    delay(DEBOUNCE_DELAY);

    if (!digitalRead(pin))
      return true;
    else
      return false;
  }
  return false;
}

char pollButtons()
{
  char output = '~';
  output = (buttonRead(FIRE)) ? FIRE_CHAR : ' ';
  output = (buttonRead(SCOPE)) ? SCOPE_CHAR : ' ';
  output = (buttonRead(RELOAD)) ? RELOAD_CHAR : ' ';

  if (buttonRead(SELECT_1) == false && buttonRead(SELECT_2) == false)
  {
    output = (buttonRead(FUNC_1)) ? JUMP_CHAR : ' ';
    output = (buttonRead(FUNC_2)) ? CROUCH_CHAR : ' ';
    output = (buttonRead(FUNC_3)) ? GRENADE_CHAR : ' ';
    output = (buttonRead(FUNC_4)) ? KNIFE_CHAR : ' ';
  }
  if (buttonRead(SELECT_1) == true && buttonRead(SELECT_2) == false)
  {
    output = (buttonRead(FUNC_1)) ? WALK_CHAR : ' ';
    output = (buttonRead(FUNC_2)) ? SPRINT_CHAR : ' ';
    output = (buttonRead(FUNC_3)) ? PREVIOUS_WEAPON_CHAR : ' ';
    output = (buttonRead(FUNC_4)) ? NEXT_WEAPON_CHAR : ' ';
  }
  if (buttonRead(SELECT_1) == false && buttonRead(SELECT_2) == true)
  {
    output = (buttonRead(FUNC_1)) ? EXTRA_1_CHAR : ' ';
    output = (buttonRead(FUNC_2)) ? EXTRA_2_CHAR : ' ';
    output = (buttonRead(FUNC_3)) ? EXTRA_3_CHAR : ' ';
    output = (buttonRead(FUNC_4)) ? EXTRA_4_CHAR : ' ';
  }

  if (buttonRead(SELECT_1) == true && buttonRead(SELECT_2) == true)
    output = 'E';

  return output;
}

void setWifiStrengthLED(uint8_t led = 4)
{
  digitalWrite(LEDR_PIN, LOW);
  digitalWrite(LEDG_PIN, LOW);
  digitalWrite(LEDB_PIN, LOW);

  switch (led)
  {
  case 0:
    digitalWrite(LEDR_PIN, HIGH);
    break;
  case 1:
    digitalWrite(LEDR_PIN, HIGH);
    digitalWrite(LEDG_PIN, HIGH);
    break;
  case 2:
    digitalWrite(LEDG_PIN, HIGH);
    break;
  default:
    digitalWrite(LEDR_PIN, HIGH);
    digitalWrite(LEDG_PIN, HIGH);
    digitalWrite(LEDB_PIN, HIGH);
  }
}

void soundBuzzer(uint8_t times = 3, uint32_t delayTime = 1000)
{
  // Approximately 50% duty cycle @ 1KHz
  for (uint8_t i = 0; i < times; i++)
  {
    digitalWrite(BUZZER_PIN, HIGH);
    delayMicroseconds(500);
    digitalWrite(BUZZER_PIN, LOW);
    delayMicroseconds(1000 - 500);

    delay(delayTime);
  }
}

#define NUM_SAMPLES 5
#define LOW_VLTG_THRESH 3.20

bool isBatteryVoltageLow()
{
  double batteryVoltage = 0;

  // Approx LiPo battery discharge curve: y = 0.003488 x − 0.227906
  // Better solution: Battery Management IC with over-voltage, under-voltage and over-temperature detection
  for (int i = 0; i < NUM_SAMPLES; i++)
  {
    batteryVoltage += (0.003488 * analogRead(BATT_ADC_PIN) - 0.227906) * 2;
  }

  return ((batteryVoltage / NUM_SAMPLES) <= LOW_VLTG_THRESH) ? true : false;
}

IMU _IMU;
Fusion _Fusion;

uint8_t broadcastAddress[] = {0x32, 0xAE, 0xA4, 0x07, 0x0D, 0x66};

typedef struct struct_payload
{
  uint8_t id;
  char action;
} struct_payload;

struct_payload payload;
esp_now_peer_info_t peerInfo;

void OnDataSent(const uint8_t *mac_addr, esp_now_send_status_t status)
{
  Serial.print("\r\nLast Packet Send Status:\t");
  Serial.println(status == ESP_NOW_SEND_SUCCESS ? 1 : 0);
}

void setup()
{
  Serial.begin(115200);

  // Setup analog read resolution to 12 bits
  analogReadResolution(12);

  //Setup buttons, LEDs & buzzer
  pinMode(B11_PIN, INPUT_PULLUP);
  pinMode(B12_PIN, INPUT_PULLUP);
  pinMode(B13_PIN, INPUT_PULLUP);
  pinMode(B14_PIN, INPUT_PULLUP);

  pinMode(B21_PIN, INPUT_PULLUP);
  pinMode(B22_PIN, INPUT_PULLUP);
  pinMode(B23_PIN, INPUT_PULLUP);

  pinMode(B31_PIN, INPUT_PULLUP);
  pinMode(B32_PIN, INPUT_PULLUP);
  pinMode(B33_PIN, INPUT_PULLUP);

  pinMode(LEDR_PIN, OUTPUT);
  pinMode(LEDG_PIN, OUTPUT);
  pinMode(LEDB_PIN, OUTPUT);

  pinMode(LAZER_PIN, OUTPUT);
  pinMode(BUZZER_PIN, OUTPUT);

  // Setup IMU
  if(_IMU.checkID()) {
    Serial.println("Unable to connect with IMU");
  }

  // Setup ESP-NOW
  WiFi.mode(WIFI_STA);

  if (esp_now_init() != ESP_OK)
  {
    Serial.println("Error initializing ESP-NOW");
    return;
  }

  esp_now_register_send_cb(OnDataSent);

  // Connect with ESP-NOW peer
  memcpy(peerInfo.peer_addr, broadcastAddress, 6);
  peerInfo.channel = 0;
  peerInfo.encrypt = false;

  if (esp_now_add_peer(&peerInfo) != ESP_OK)
  {
    Serial.println("Failed to add peer");
    return;
  }

  Serial.println("Setup complete!");
}

void loop()
{
 
  // Collect data from IMU
  _IMU.readDataAccelerometer();
  _IMU.readDataGyroscope();
  _IMU.readDataMagnetometer();

  // Determine mouse movement using the IMU
  payload.id = 0;

  clock_t timestamp = clock();                                          // Gyroscope timestamp
  FusionVector gyroscope = {_IMU.accel_x, _IMU.accel_y, _IMU.accel_z};  // Gyroscope data in degrees/s
  FusionVector accelerometer = {_IMU.gyro_x, _IMU.gyro_y, _IMU.gyro_z}; // Accelerometer data in g
  FusionVector magnetometer = {_IMU.mag_x, _IMU.mag_y, _IMU.mag_z};     // Magnetometer data in arbitrary units

  _Fusion.updateOrientation(gyroscope, accelerometer, magnetometer, timestamp);

  printf("Roll %0.1f, Pitch %0.1f, Yaw %0.1f", _Fusion.roll, _Fusion.pitch, _Fusion.yaw);

  uint8_t x_movement = _Fusion.pitch / 10;
  uint8_t y_movement = _Fusion.yaw / 10;
  uint8_t movement = x_movement & 0x0F || y_movement & 0x0F << 4;

  payload.action = movement; 
  esp_err_t result = esp_now_send(broadcastAddress, (uint8_t *)&payload, sizeof(payload));

  if (result != ESP_OK)
    Serial.println("Error sending data over ESP-NOW");

  // Check for button presses
  char key = pollButtons();
  if( key != '~') {
      payload.id = 1;
      payload.action = key;

      esp_err_t result = esp_now_send(broadcastAddress, (uint8_t *)&payload, sizeof(payload));

      if (result != ESP_OK)
        Serial.println("Error sending data over ESP-NOW");
  }

  // Check WiFi strength and update RGB LED
  int8_t RSSI = WiFi.RSSI();
  if (RSSI < -70)
    setWifiStrengthLED(0);
  else if (RSSI < -67)
    setWifiStrengthLED(1);
  else if (RSSI < -30)
    setWifiStrengthLED(2);
  else
    setWifiStrengthLED(3);

  // Check battery and sound buzzer if low
  if (isBatteryVoltageLow()) {
    soundBuzzer();
  }

  delay(LOOP_DELAY);
}

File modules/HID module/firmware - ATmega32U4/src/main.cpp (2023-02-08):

#include <Arduino.h>
#include "connections.h"
#include "key-map.h"

#include <Mouse.h>
#include <Keyboard.h>
#include <U8glib.h>

// TODO
// - Create a menu interface using display and buttons: https://github.com/olikraus/u8glib/blob/master/sys/arm/examples/menu/menu.c
// - Create a library for keyboard mappings for various games

#define DEBOUNCE_DELAY 300 // ms
#define LOOP_DELAY 300     // ms

bool pollButton(uint8_t button)
{
    if (!digitalRead(button))
    {
        delay(DEBOUNCE_DELAY);
        if (!digitalRead(button))
            return true;
        else
            return false;
    }
    return false;
}

void blinkLED()
{
    digitalWrite(LED_K, HIGH);
    delay(100);
    digitalWrite(LED_K, LOW);
    delay(100);
}

void setup()
{
    Serial.begin(115200);

    pinMode(BTN_NEXT, INPUT_PULLUP);
    pinMode(BTN_OK, INPUT_PULLUP);

    pinMode(LED_K, OUTPUT);

    Mouse.begin();
    Keyboard.begin();
}

void loop()
{
    char c = '-';
    if (Serial.available())
        c = Serial.read();

    // Keyboard keypresses
    switch (c)
    {
    case 'F':
        Mouse.click(ACTION_FIRE); // Fire
        blinkLED();
        break;
    case 'O':
        Mouse.click(ACTION_SCOPE); // Scope
        blinkLED();
        break;
    case 'R':
        Keyboard.write(ACTION_SCOPE); // Reload
        blinkLED();
        break;
    case 'E':
        Keyboard.write(ACTION_ESC);
        blinkLED();
        break;

    case 'J':
        Keyboard.write(ACTION_JUMP);
        blinkLED();
        break;
    case 'W':
        Keyboard.write(ACTION_WALK);
        blinkLED();
        break;
    case 'A':
        Keyboard.write(ACTION_EXTRA1);
        blinkLED();
        break;

    case 'C':
        Keyboard.write(ACTION_CROUCH);
        blinkLED();
        break;
    case 'S':
        Keyboard.write(ACTION_SPRINT);
        blinkLED();
        break;
    case 'B':
        Keyboard.write(ACTION_EXTRA2);
        blinkLED();
        break;

    case 'G':
        Keyboard.write(ACTION_GRENADE);
        blinkLED();
        break;
    case 'P':
        Keyboard.write(ACTION_PREV_WEAPON);
        blinkLED();
        break;
    case 'X':
        Keyboard.write(ACTION_EXTRA3);
        blinkLED();
        break;

    case 'K':
        Keyboard.write(ACTION_KNIFE);
        blinkLED();
        break;
    case 'N':
        Keyboard.write(ACTION_NEXT_WEAPON);
        blinkLED();
        break;
    case 'Y':
        Keyboard.write(ACTION_EXTRA4);
        blinkLED();
        break;
    }

    // Mouse movement
    if(c == '~') {
        uint8_t movement = 0;
        if (Serial.available())
            movement = Serial.read();

        uint8_t movement_x = movement & 0x0F;
        uint8_t movement_y = movement & 0xF0 >> 4;

        Mouse.move(movement_x, movement_y);
    }

    delay(LOOP_DELAY);
}

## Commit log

2021-12-07 Datasheets, reference circuit images and character-set spreadsheet added
    [character-set.xlsx]
2021-12-09 HID module files added
    [board.kicad_pcb, board.sch]
2021-12-09 Controller module files added
    [BMS.sch, DW01A.step, FS8205A.step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]
2021-12-09 Pedometer module files added
    [BMS.sch, DW01A.step, FS8205A.step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]
2022-12-06 Pedometer module: Schematic and PCB layout
    [BMS.sch, IMU.sch, board.kicad_pcb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]
2022-12-06 HID module: Schematic and PCB layout
    [board.kicad_pcb, board.sch]
2022-12-06 Controller module: Schematic and PCB layout
    [BMS.sch, IMU.sch, board.kicad_pcb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]
2022-12-06 Pedometer module: PCB size reduced
    [BMS.sch, IMU.sch, board.kicad_pcb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]
2022-12-06 Controller module: PCB complete
    [BMS.sch, IMU.sch, board.dsn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]
2022-12-06 HID module: PCB complete
    [board.dsn, board.kicad_pcb, board.sch]
2022-12-06 Pedometer module: PCB complete
    [IMU.sch, board.dsn, board.kicad_pcb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]
2022-12-06 Controller module: PCB modular
    [BMS.sch, board.dsn, board.kicad_pcb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]
2022-12-06 HID module: PCB modular
    [board.dsn, board.kicad_pcb, board.sch]
2022-12-06 Pedometer module: PCB modular
    [BMS.sch, IMU.sch, board.dsn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]
2023-02-05 PCB: IMU
    [BMS.sch, IMU.sch, board.dsn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]
2023-02-05 PCB: USB receptacle moved closer to PCB edge
    [board.dsn, board.kicad_pcb, board.sch]
2023-02-09 Controller module: Button PCB
    [board.dsn, board.kicad_pcb, board.sch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]
2023-02-10 HID module: Enclosure
    [enclosure.f3d]
2023-02-10 Pedometer module: Enclosure
    [enclosure.f3d]
2023-04-24 Controller module: Enclosure
    [Buffer_tube.stl, Disconnector.stl, End_plate.stl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]
2025-09-13 Controller module: Optical Flow Sensor Connector
2025-09-13 HID enclosure options
2025-09-13 Pedometer enclosure options
2025-09-13 Rescue connector symbols
